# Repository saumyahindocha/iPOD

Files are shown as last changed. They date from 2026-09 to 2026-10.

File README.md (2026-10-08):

# iPOD — a DIY handheld music player

> A pocket-sized modern iPod built from scratch: Raspberry Pi Pico 2 W, Bluetooth streaming, hi-fi I2S DAC, and a touchscreen that shows album art.

A pocket-sized "modern iPod" built around the Raspberry Pi Pico 2 W. Pod receives audio from a phone over Bluetooth, plays it through a hi-fi I2S DAC, and shows album art on a touchscreen.

**Status:** breadboard prototyping. A custom PCB comes after full testing and optimisation on the breadboard.

## Goals

- **Bluetooth A2DP sink (core requirement):** phone → Pico 2 W → DAC → headphones
- **Now Playing screen** with full-bleed album art fading into an accent colour, and centred track text ("Poster" layout)
- **SD card playback** with a library browser, and a battery gauge with low-battery warning

## Hardware

| Part | Role |
|---|---|
| Raspberry Pi Pico 2 W | Main controller, Bluetooth Classic |
| Adafruit PCM5102 I2S DAC | Audio output |
| 2.8" 240×320 SPI touch display | UI and album art |
| microSD slot (on the display module) | Local playback |

The Pico 2 W replaced an earlier ESP32-S3 plan because the ESP32-S3 has no Bluetooth Classic, which A2DP needs.

## Wiring

Pins as of the perfboard build (8 Oct 2026); `sdk/common/pod_pins.h` is the source of truth.
They were re-chosen so 7 screen pins sit directly below their Pico pin on the perfboard;
see [docs/perfboard_build.pdf](docs/perfboard_build.pdf). The old breadboard layout is in git history.

### Display + touch (shared SPI0)

| Display pin | Pico 2 W |
|---|---|
| VCC | 3V3 (pin 36) |
| GND | GND |
| CS | GP12 (pin 16) |
| RESET | GP11 (pin 15) |
| DC | GP10 (pin 14) |
| SDI (MOSI) + T_DIN | GP7 (pin 10) |
| SCK + T_CLK | GP6 (pin 9) |
| LED | GP8 (pin 11) |
| SDO (MISO) | not connected |
| T_CS | GP5 (pin 7) |
| T_DO | GP4 (pin 6) |
| T_IRQ | GP3 (pin 5) |

Touch calibration (this board): both axes are reversed. Raw X ≈ 3540 at the left edge and ≈ 565 at the right; raw Y ≈ 3680 at the top and ≈ 380 at the bottom.

### PCM5102 DAC (I2S)

| DAC pin | Pico 2 W |
|---|---|
| VIN | 3V3 (pin 36) |
| GND | GND |
| DIN | GP13 (pin 17) |
| BCK | GP14 (pin 19) |
| WSEL (LRCK) | GP15 (pin 20) |
| MCK, DE, FIL, MU, FM | not connected |

### microSD (slot on the display module)

SD_CS → GP9; shares GP6 (SCK), GP7 (MOSI) and GP4 (MISO) with the display bus.

### Battery

100k/100k divider from the switched battery to GP28 (pin 34), 100 nF across the lower resistor.
A MAX17048 breakout on GP0 (SDA) / GP1 (SCL) is used instead if fitted.

## Firmware overview

Pod has two firmware tracks:

- **`sdk/` — the main firmware** (C, Raspberry Pi Pico SDK + BTstack). A home screen picks the source:
  - **Phone:** Bluetooth audio from the iPhone with **album art over AVRCP Cover Art**, volume slider synced with the phone, press-and-hold seeking.
  - **SD card:** MP3/WAV player with a touch library browser, tags and cover art, drag-to-seek, auto-advance through a folder.
  - Poster Now Playing screen rendered on the second core, battery icon with low-battery warning.
  See [sdk/README.md](sdk/README.md) for the test plan.
- **`firmware/` — Arduino bring-up sketches** used to test each part of the hardware on its own (LED, DAC, Bluetooth, screen, touch).

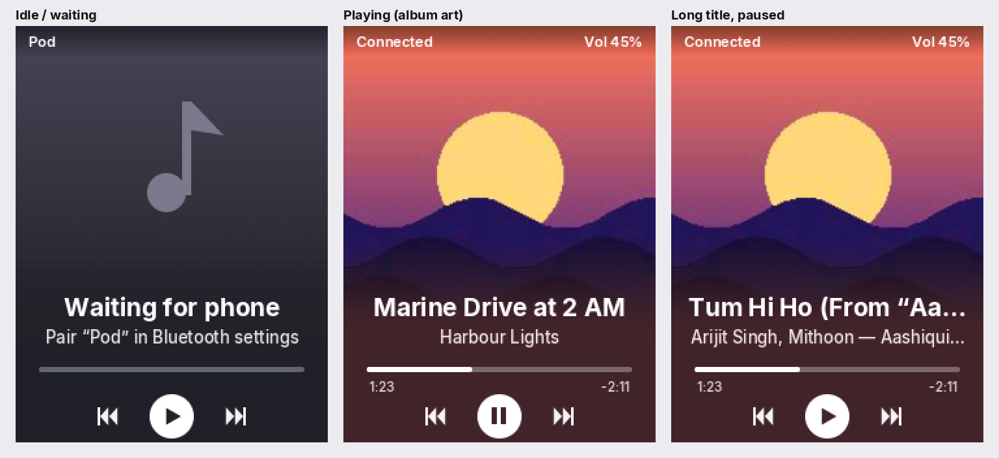
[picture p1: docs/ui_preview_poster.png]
Poster UI preview


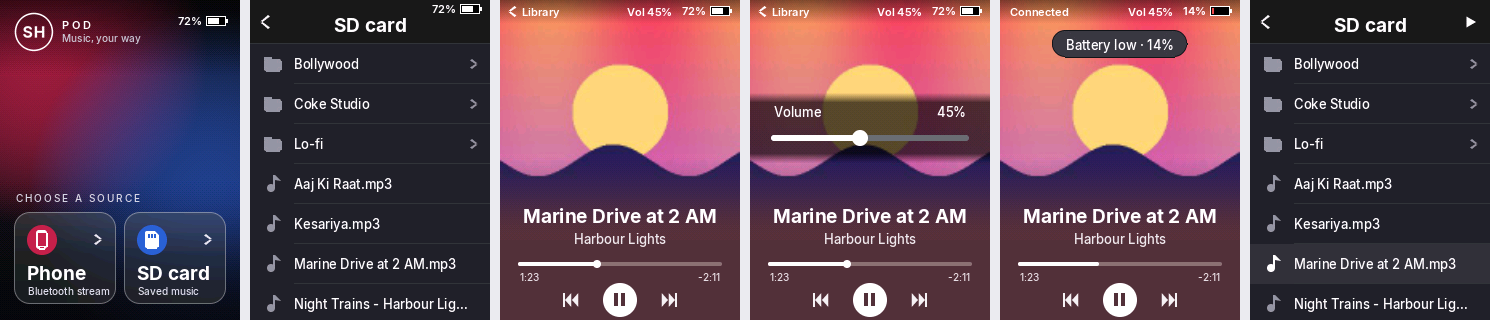
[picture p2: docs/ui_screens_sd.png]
Home, library, SD Now Playing, volume, low battery


## Building the firmware

The **Build SDK firmware** action compiles `sdk/` and publishes the `pod-sdk-firmware` artifact. The Arduino sketches are built by the **Build firmware** action as described below.

### Arduino sketches

Sketches live in `firmware/<name>/<name>.ino`. Every push that touches `firmware/` triggers the **Build firmware** GitHub Action, which compiles each sketch for the Pico 2 W with `arduino-cli` and the [arduino-pico](https://github.com/earlephilhower/arduino-pico) core. A `sketch.yaml` in a sketch folder can set its own board options (e.g. Bluetooth on), `firmware/libraries.txt` lists the Arduino libraries the build installs, and Pod's own libraries live in `firmware/libraries/` (e.g. `PodTouch`, the touch driver).

To flash: open the latest run under **Actions**, download the **pod-firmware** artifact, hold BOOTSEL while plugging in the Pico, and drag the `.uf2` onto the RP2350 drive.

| Sketch | What it does |
|---|---|
| `blink` | Blinks the onboard LED (build + flash check) |
| `tone_test` | 440 Hz tone through the DAC (I2S wiring check) |
| `bt_sink` | Bluetooth A2DP receiver named "Pod": phone → DAC → headphones |
| `display_test` | Colour test, title screen and touch dots on the ILI9341 + XPT2046 |
| `now_playing` | Bluetooth audio + Now Playing screen: track, artist, album and touch controls |

## Repository layout

```
sdk/        main firmware (Pico SDK, C)
firmware/   Arduino bring-up sketches (one folder per sketch)
.github/    GitHub Actions build
hardware/   KiCad PCB project (hardware/pod-pcb)
docs/       notes and datasheets
PROGRESS.md dated build log
```

## PCB, battery and enclosure

Rev A board (being drawn in EasyEDA Pro): a Pico 2 W soldered onto our board, the 2.8" screen module on sockets, USB-C charging, 1000 mAh LiPo with fuel gauge, PCM5102A DAC and headphone jack, play/pause button and power switch. The design spec is [docs/pcb-plan.md](docs/pcb-plan.md) and the EasyEDA workflow is [docs/easyeda-guide.md](docs/easyeda-guide.md). The older KiCad skeleton in `hardware/pod-pcb` was for a bare-RP2350 version and is no longer used.

## Progress

See [PROGRESS.md](PROGRESS.md).

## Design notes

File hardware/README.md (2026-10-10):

# hardware

| Folder | What's in it | Status |
|---|---|---|
| `perfboard/` | The build in progress: the Pico 2 W, screen, DAC and TP4056 charger on a 20 × 43-hole perfboard. The full guide (solder view, hole-by-hole map, front view, off-board wires, shopping list) is [`../docs/perfboard_build.pdf`](../docs/perfboard_build.pdf); `dac_wiring.pdf` is the stand-alone DAC sheet; `tools/` has the scripts that draw them | **Building** |
| `pod-pcb-easyeda/` | Rev A custom PCB drawn in EasyEDA Pro: 4-page schematic, assembly drawing, 1:1 fit test, and `fab/` with the Gerbers (outline fixed), BOM and pick-and-place, ready for JLCPCB | Designed, not ordered (about $90 assembled) |
| `pod-pcb/` | Early KiCad skeleton for a bare-RP2350 board | Superseded |

The design spec for the PCB is [`../docs/pcb-plan.md`](../docs/pcb-plan.md); the EasyEDA walkthrough is [`../docs/easyeda-guide.md`](../docs/easyeda-guide.md).
Pin assignments for both builds live in [`../sdk/common/pod_pins.h`](../sdk/common/pod_pins.h).

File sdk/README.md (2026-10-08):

# Pod bring-up kit: Pico 2 W + PCM5102 + 2.8" ILI9341/XPT2046

Pod's main firmware for **the breadboard wiring below**, built against **Pico SDK 2.3.1** and
**pico-extras sdk-2.3.1** for board `pico2_w`. They compile cleanly, and the
screen renderer was checked pixel-for-pixel on a PC, but they have **not been run
on real hardware yet**. Your breadboard is the first test.

| Firmware (`pod-sdk-firmware` artifact in Actions) | What it tests |
|---|---|
| `pod_display_test.uf2` | Screen + touch only: colours, geometry, touch calibration, paint |
| `pod_dac_test.uf2` | DAC only: quiet 440 Hz tone, LEFT → RIGHT → BOTH → silence |
| `pod.uf2` | **The main firmware.** Home screen → **Phone** (iPhone → Bluetooth → DAC with album art) or **SD card** (MP3/WAV player with library browser). Poster Now Playing screen, volume slider, seeking, battery icon |

---

## 1. Wiring (single source of truth: `common/pod_pins.h`)

Pico 2 W physical pin numbers are in brackets. GND pins: 3, 8, 13, 18, 23, 28, 33, 38.
**Never use GP23, GP24, GP25 or GP29.** The radio uses them.

Pins changed on 8 Oct 2026 for the perfboard build (7 screen pins sit directly below their
Pico pin there; see `docs/perfboard_build.pdf`). The breadboard layout is in git history.

### Display + touch (both on SPI0)
| Module pin | Pico 2 W | Note |
|---|---|---|
| VCC | 3V3 OUT (36) | |
| GND | GND | |
| CS | GP12 (16) | |
| RESET | GP11 (15) | |
| DC | GP10 (14) | |
| SDI(MOSI) | GP7 (10) | shared with T_DIN and SD_MOSI |
| SCK | GP6 (9) | shared with T_CLK and SD_SCK |
| LED | GP8 (11) | backlight (PWM) |
| SDO(MISO) | **not connected** | doesn't release the line; would corrupt touch readings |
| T_CLK | GP6 (9) | shared with SCK |
| T_CS | GP5 (7) | |
| T_DIN | GP7 (10) | shared with SDI |
| T_DO | GP4 (6) | SPI0 RX; shared with SD_MISO |
| T_IRQ | GP3 (5) | |

### PCM5102 DAC (Adafruit)
| DAC pin | Pico 2 W |
|---|---|
| VIN | 3V3 OUT (36) |
| GND | GND |
| DIN | GP13 (17) |
| BCK | GP14 (19) |
| WSEL | GP15 (20) (must be BCK + 1) |
| MCK, DE, FIL, MU, FM | leave unconnected |

Listening: DAC jack → headphones or a powered speaker (line level).

### SD card slot (on the back of the display module, shares SPI0)
| SD pin (4-pin header next to the card slot) | Pico 2 W |
|---|---|
| SD_CS | GP9 (12) |
| SD_SCK | GP6 (9) |
| SD_MOSI | GP7 (10) |
| SD_MISO | GP4 (6) |

### Battery level
Perfboard: 100k/100k divider from the switched battery to GP28 (34), 100 nF across the lower
resistor; the firmware reads it at start-up if it sees a voltage there. Optional instead: a
MAX17048 breakout on SDA → GP0 (1), SCL → GP1 (2). With neither, the battery icon stays hidden.

## 2. Before powering up (5 minutes, prevents most problems)
1. **Unplug USB.** Multimeter on resistance/continuity: 3V3 (36) to GND must NOT
   beep (no short). VBUS (40) to GND must NOT beep.
2. Continuity-check every jumper from the module pin to the Pico pin, especially
   the shared SCK/T_CLK and SDI/T_DIN connections.
3. Install a serial monitor: VS Code + Raspberry Pi Pico extension (built-in
   Serial Monitor), PuTTY, or the Arduino IDE Serial Monitor. The Pico appears
   as a COM port once running (any baud setting works over USB).

**Flashing any UF2:** hold **BOOTSEL**, plug in USB, release, then drag the
`.uf2` onto the `RP2350` drive. The board reboots by itself. Open the serial
monitor within ~1 s to catch the first lines.

---

## 3. Test sequence: one part at a time

### Step 1: screen + touch → `pod_display_test.uf2`
Pass criteria:
- Full-screen RED, GREEN, BLUE, WHITE, BLACK in that order (serial names each one).
- A white border with coloured corners: RED top-left, GREEN top-right, BLUE bottom-left, WHITE bottom-right.
- Tap the 4 yellow crosshairs. Serial prints a calibration block.
- Paint mode: dots land under the stylus. The red box clears the screen.

If it fails:
- White screen: SCK/MOSI/CS/DC/RESET wiring.
- Black screen: LED or VCC.
- Red and blue swapped: change `0x48` to `0x40` in `common/ili9341.c`.
- Touch dead: T_CS/T_DO/T_IRQ wiring. Check that the display's SDO is really disconnected.
- Speckles or garbage: lower `POD_TFT_BAUD` to 20 MHz in `pod_pins.h`.

### Step 2: DAC → `pod_dac_test.uf2`
A quiet tone plays: left ear, right ear, both, silence, repeating.
- Left and right swapped: BCK and WSEL are swapped.
- Silence: check DIN/BCK/WSEL and VIN.

### Step 3: Bluetooth + Poster UI → `pod.uf2`, choose **Phone**
1. **First boot runs touch setup:** tap the 4 dots. The calibration is saved to
   flash. To redo it later, **hold a finger on the screen for 2 seconds while plugging in USB**.
2. The **home screen** (SH logo, wallpaper, two glass buttons) asks Phone or SD card: tap **Phone**. The idle screen reads **"Waiting for phone"**.
   Tapping the **house icon** (top-left on Now Playing, top-right in the library) goes back to the home screen.
3. On the iPhone, go to Settings → Bluetooth and tap **"Pod xx:xx:…"**. If you
   paired an earlier Pod build, first open it there and choose **"Forget This
   Device"**, because iOS caches the old feature list.
4. Play something in Spotify. Within about 1–2 s you should see:
   - the album art full-bleed, fading into a colour taken from the cover
   - title, artist, the moving progress bar with elapsed and remaining time
   - serial lines: `Cover Art : connection established`, then `downloading thumbnail`, then
     `album art 200x200 … decoded`, then `frame rendered in N ms`
5. Tap **prev / play-pause / next** at the bottom of the screen. Spotify should
   respond. Serial: `Pod: touch command N sent`.
   **Press and hold** prev / next to rewind / fast-forward (release to stop).
   How far it scrubs depends on the app; Bluetooth has no "jump to time" command.
6. Move the iPhone volume slider. "Vol NN%" updates and the loudness changes.
7. **Tap the album art** to open the Pod's volume slider and drag it. The sound changes
   and the iPhone's volume slider follows. It closes by itself after 3 s.

---

### Home screen wallpaper (optional)
The home screen shows a full-screen picture behind the SH logo and the two glass buttons. Without one,
it shows generated garnet-and-blue art. To install your own (it lives in its own flash area, so
firmware updates don't erase it, and the picture never goes into the repo):

```
python3 tools/make_wallpaper.py my_photo.jpg --focus 0.55 --preview check.png
```
`--focus` picks the vertical crop (0 = top, 1 = bottom); look at `check.png`, then flash
`wallpaper.uf2` like firmware (BOOTSEL, drag). Flash `pod.uf2` again afterwards if needed; the two
never overwrite each other.

### Step 4: SD card player → `pod.uf2`, choose **SD card**
**Card:** FAT32 or exFAT, any size. Copy MP3 (CBR or VBR) or WAV (16/24-bit) files; folders are fine.
For cover art, embed a **baseline JPEG up to 32 KB** (about 300–500 px) in the MP3, or put
`cover.jpg` / `folder.jpg` in the album folder. Progressive JPEGs and PNGs show the placeholder.

1. Tap **SD card** on the home screen. The library lists folders first, then songs, A–Z.
   Drag to scroll, tap a folder to open it, **<** (top-left) to go up; at the top level it goes home.
2. Tap a song: it plays and the Poster screen shows its title, artist and cover.
   Serial: `Pod: SD card ready`, `Pod: playing /…/song.mp3 (MP3 44100 Hz, … ms)`.
3. **Drag the knob on the progress bar** to jump anywhere in the song.
4. **Hold ⏭ / ⏮** to scrub 5 s at a time; tap to skip. ⏮ restarts the song if more than 3 s in.
5. Tap the art for the volume slider. **< Library** (top-left) goes back to the list;
   the ▶ in the list header returns to the song.
6. At the end of a song the next one in the folder plays; at the end of the folder it stops.

Troubleshooting: "No SD card" → check SD_CS (GP7) and the three shared wires; "Card isn't FAT32 /
exFAT" → reformat; crackles while the screen redraws → report it (the display releases the bus every
24 rows, so this shouldn't happen).

### Battery icon and low-battery warning
With the gauge fitted, the status bar shows the percentage and a battery icon (green while
charging). Below **15 %** a "Battery low" message pops up once; it re-arms after charging.

## 4. Robustness tests (do all of these before the PCB)
| Test | Expected |
|---|---|
| 30-minute continuous play | No dropouts, clicks or resets |
| Skip tracks 10× quickly | Art and text catch up to the final track |
| Walk out of range (~10 m, a wall), come back | Audio stops, then reconnects |
| iPhone Bluetooth off/on | Pod returns to "Waiting…", then reconnects |
| Unplug and replug Pod | iPhone reconnects without re-pairing (keys are in flash) |
| Phone call during playback | Music pauses; call audio stays on the iPhone (call audio over Bluetooth isn't supported, by design) |
| Track with no artwork / podcast | Placeholder note is shown, no crash |
| Hindi/Devanagari title | Shows `?`. Expected for now (font has Latin only) |

## 5. Measure & tune (numbers to bring to the PCB design)
- **Screen SPI speed:** raise `POD_TFT_BAUD` from 30 MHz to 40 MHz, then 62.5 MHz. Keep the highest
  speed with zero glitches. Short PCB traces will allow the top speed.
- **Render time:** from `frame rendered in N ms` on serial. Target < 150 ms.
- **Audio glitches during track changes** (when art is drawn): there should be none,
  because drawing runs on the second core. Report it if you hear any.
- **Current draw:** use a USB power meter, or a multimeter in series with 5 V. Measure
  idle, streaming, and streaming with the backlight off. These numbers size the
  battery and regulator.
- **Bluetooth range:** in open space and through one wall. It depends on antenna
  placement, which matters for the PCB/enclosure.

Write these numbers down; they are the inputs to the PCB design phase.

---

## What's in the firmware

**SD mode** (`sd_player/`): FatFs (read-only, FAT32 + exFAT) over a small SPI SD driver; minimp3 for MP3,
WAV 16/24-bit; ID3v2.2–2.4 + ID3v1 + WAV INFO tags; Xing/VBRI headers for exact duration and VBR
seeking. `tools/test_track_meta.c` tests this on a PC against real files; `tools/preview/` renders the
screens on a PC.

**Phone mode** (vs. upstream `a2dp_sink_demo`)
All changes are marked `Pod patch`.
1. **Software volume.** Upstream ignores volume, which makes the iPhone slider do nothing at full scale.
2. **Sample-rate change handling** (44.1/48 kHz) so audio never plays at the wrong pitch.
3. **Album art over Bluetooth** (AVRCP Cover Art), downloaded to RAM automatically on every track change.
4. **Option C Poster UI on core 1:** 240×240 art, smoothstep fade into an accent
   colour, dithered gradients, anti-aliased Inter text, live progress, touch
   controls. Core 0 keeps Bluetooth and audio. Touch calibration is stored in flash.
5. Device name "Pod", logs over USB serial.

## Rebuilding

**On GitHub (normal way):** every push that changes `sdk/` runs the **Build SDK firmware**
action. Download the `pod-sdk-firmware` artifact from the run and drag the `.uf2` onto the Pico.

**Locally:**
Install the **Raspberry Pi Pico** VS Code extension (SDK 2.3.1 + toolchain), then:
```
git clone -b sdk-2.3.1 https://github.com/raspberrypi/pico-extras.git
cmake -B build -G Ninja -DPICO_SDK_PATH=... -DPICO_EXTRAS_PATH=... -DCMAKE_BUILD_TYPE=Release
ninja -C build
```
Fonts are pre-generated. To change sizes or weights, edit `tools/gen_fonts.py` and run
`python3 tools/gen_fonts.py` (needs Pillow).

## Credits / licences
Inter font: SIL Open Font License (`third_party/inter/LICENSE.txt`). TJpgDec
by ChaN (`third_party/tjpgd/LICENSE.txt`). BTstack via the Pico SDK (Raspberry
Pi's licence covers RP2xxx use). 8x8 font in the test app: public domain.

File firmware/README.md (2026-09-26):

# firmware
Pico 2 W source code goes here.

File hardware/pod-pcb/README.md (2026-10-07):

# Pod PCB (Rev A)

KiCad project for the Pod board. **The spec it follows is [docs/pcb-plan.md](../../docs/pcb-plan.md)**:
RP2350A + RM2 Bluetooth, PCM5102A DAC, BQ24074 USB-C charging with power path, MAX17048 fuel gauge,
TPS63802 3.3 V buck-boost, 16 MB flash + 8 MB PSRAM, sockets for the 2.8" ILI9341 screen module,
play/pause button and power/hold switch. 4 layers, 0.8 mm, 50 × 94 mm.

| File | What's in it |
|---|---|
| `pod-pcb.kicad_pro` | Project, with JLCPCB-friendly rules and net classes (Power, USB) |
| `pod-pcb.kicad_sch` | Overview sheet linking the five blocks |
| `power.kicad_sch` … `screen_controls.kicad_sch` | One sheet per block, each with its checklist printed on it |
| `pod-pcb.kicad_pcb` | 4-layer board: outline, module area, M3 holes, battery area, RM2 antenna keep-out |

**Designing in EasyEDA instead?** Follow [docs/easyeda-guide.md](../../docs/easyeda-guide.md); the spec is the same.

**Workflow (KiCad):** open the project in KiCad 9 (it upgrades these KiCad 7 files), draw one sheet to its
checklist, delete the checklist box, commit and push. Each sheet is reviewed against the spec before
the next one. Start with **Power**.

Before routing, measure the screen module (outline, hole centres, header positions) and update
the outline, the holes and the J3/J4 socket positions.

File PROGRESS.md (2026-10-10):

# Pod — build log

Newest entries at the top. Each entry: what was done, what broke, what's next.

## 2026-10-10 (later) — Device built and touch working

**Done**
- Whole perfboard built in one night: Pico, screen, DAC, links and wires; powered from the Pico's USB until the battery arrives (TP4056 and battery not fitted yet, firmware hides the battery icon)
- Firmware boots to the home screen on the new pin map; touch now works after a fresh 4-dot calibration

**Fixed**
- Touch read nothing: the data link from Pico pin 6 (GP4) to the screen's T_DO (perfboard holes F8–F9–F10) was open. The pressed signal (T_IRQ) worked, so the setup dots "accepted" garbage readings (all 0 or all 8191) and the home screen rightly refused the resulting calibration. Found by printing the raw readings on the screen; fixed by resoldering the link
- Firmware hardening from the hunt: MISO pulled up; a tap counts on Z1 alone (Z2 unreliable here); readings above 4095 rejected as "line open"; new calibration magic so the stale breadboard calibration is ignored; battery init runs after the home screen
- Two diagnostic firmwares added: `pod_touch_doctor` (names the wire to check) and `pod_touch_setup` (calibrate with live raw numbers, test, save)

**Next**
- Test SD playback and Bluetooth from the phone
- Software design updates and new features (Ash's list)
- Fit the TP4056, switch and battery when they arrive

## 2026-10-10 — Perfboard build under way

**Done**
- Started soldering the perfboard: screen sockets in and the screen fitted, DAC mounted under the screen with its jack at the board edge
- Got the DAC's real pin order from Adafruit's own board files (two rows: DE/FIL/MCK/MU/FM/3V, and VIN/GND/WSEL/DIN/BCK/Lout/G/Rout) and matched it to photos of the build
- DAC added to the main perfboard guide: pins in holes N34–N39 and T35–T40, five numbered wires (12–16) to Pico pins 36, 18, 20, 17, 19; hole map and front view updated. Multimeter check before wiring: N35 (GND) must beep to the jack's sleeve
- Battery divider now uses two 150 kΩ resistors (on hand); firmware detection threshold lowered so 100–150 kΩ dividers are found even on a low battery. Local build passes
- Repo tidy-up: `hardware/pod-pcb-easyeda/` holds the finished PCB design (schematic, assembly drawing, 1:1 fit test, Gerbers with the outline fix, BOM, pick-and-place) so it can be ordered later; `hardware/perfboard/` holds the DAC sheet and the scripts that draw the build guide

**Notes**
- Spare 10 µF / 100 µF electrolytics aren't suitable for the 100 nF filter on the battery divider (their leakage would read the battery low); buy a 100 nF ceramic or leave it out

**Next**
- Finish the 7 links and wires 1–11, test screen, touch and SD on USB power
- Solder the DAC pins, check N35 to the jack sleeve, then wires 12–16 and test audio
- TP4056, switch and battery last, after the continuity checks in the guide

## 2026-10-08 (later) — Switched to a perfboard build

**Done**
- JLCPCB quote for the assembled PCB came to about $90, too much for one prototype; the PCB design stays in the repo for later
- Planned a perfboard version with the same layout and the same Pico pins (`docs/perfboard_build.pdf`): Pico 2 W in sockets at the top, screen on sockets below it, TP4056 USB-C charger and the Adafruit PCM5102 DAC at the bottom edge, 1000 mAh LiPo on the back
- Power: TP4056 OUT+ → slide switch → 1N5819 → VSYS, so the Pico's USB can stay plugged in for flashing; 100k/100k divider on GP28 for the battery level
- Re-chose the GPIO map so 7 screen pins sit directly under their Pico pins (short solder links instead of wires): on-board wires down from 18 to 11. Display on SPI0 GP4/6/7, CS GP12, DC GP10, RST GP11, LED GP8, T_CS GP5, T_IRQ GP3, SD_CS GP9; DAC DIN GP13, BCK GP14, WSEL GP15. Firmware pins and CMake I2S pins updated; local build passes
- Firmware reads the battery from the GP28 divider when no MAX17048 answers (percent from a LiPo voltage curve, charging inferred from rising voltage); the optional gauge moved to GP0/GP1

**Next**
- Buy parts, build, test screen/touch/SD on USB power first, then audio, then battery
- Check the battery percentage against a multimeter once the battery is in

## 2026-10-08 — PCB routed and exported

**Done**
- Switched the board to carry the Pico 2 W itself (soldered on through its headers) instead of a bare RP2350; dropped the TPS63802 regulator and USB ESD chip (USB-C is charge-only)
- All four schematic sheets drawn and reviewed: Power, Pico, Audio (PCM5102A + PJ-342 jack with headphone detect), Screen (14-pin and 4-pin sockets, play button)
- PCB 52 × 109 mm, 2 layers: placed, autorouted with hand-drawn power stubs between the Pico pins, GND pours on both layers, antenna notch and keep-out. DRC clean apart from the expected notch item
- Exported Gerbers, BOM (23 lines, all LCSC) and pick-and-place; checked drill sizes, outline, copper and positions

**Fixed in review**
- Many routing problems: power nets too wide to pass between header pins (power width 0.4 mm plus 0.3 mm stubs), GND islands, duplicate vias, stitching vias with no copper, pours not rebuilt
- Gerber outline had a stray 6.35 mm line from the jack footprint, 2.2 mm inside the bottom edge, which the fab would have milled as a slot; removed from the outline file

**Next**
- Paper 1:1 fit test with the Pico and screen module, then order from JLCPCB (top-side assembly; hand-solder the Pico and screen sockets)
- Firmware: headphone detect, charge/power-good status, play button

## 2026-10-07 (evening) — Power sheet drawn in EasyEDA

**Done**
- Moved PCB design to EasyEDA Pro (online); wrote a beginner guide with click-by-click checklists (`docs/easyeda-guide.md`)
- Sheet 1 (Power) drawn and reviewed: USB-C + ESD, BQ24074 charger, battery connector, power switch, TPS63802 3.3 V regulator, MAX17048 gauge
- Resistor values changed to standard JLCPCB Basic parts: ISET 1.8 kΩ (0.49 A charging), ILIM 1.2 kΩ (1.34 A input limit), regulator feedback 56 kΩ / 10 kΩ (still 3.30 V)

**Fixed in review**
- Charger IN, the second OUT pin and the second BAT pin were unconnected; the two 22 µF output capacitors were in series; the gauge's 1 µF capacitor was missing; regulator PG label added

**Changed**
- Switched the board to Ash's own **Pico 2 W**, soldered on, instead of a bare RP2350A + RM2 radio: no chip, flash, PSRAM, crystal, radio or 3.3 V regulator to design, and 2 layers instead of 4
- The Pico sits in a 23 mm strip above the screen module with a 9 × 14 mm cut-out under its antenna (Raspberry Pi's carrier-board rule); board 52 × 109 mm, Pod about 57 × 115 × 24 mm
- Power: charger output feeds the Pico's VSYS; the power switch grounds the Pico's 3V3_EN; the Pico's 3V3 pin powers the screen, DAC and gauge. USB-C charges, the Pico's micro-USB programs
- Same GPIOs as the breadboard, so `pod.uf2` runs unchanged

- All four schematic pages drawn in EasyEDA and reviewed: Power, Pico (as two 1×20 through-hole headers J6/J7, LCSC C50981), Audio (PCM5102A, PJ-342 jack C668606 with detect on its switch contact), Screen (sockets C5307340 / C2897367, side button C530670)

**Next**
- Export the BOM for a part check; convert to PCB and place parts using the layout in `docs/pcb-plan.md`

## 2026-10-07 (later) — Home screen, SD player, battery

**Done (built and tested on a PC, waiting for the SD card + wires to test on hardware)**
- Home screen: choose **Phone** or **SD card**; tapping the top-left corner returns to it
- Home screen redesign: full-screen wallpaper (installed separately as `wallpaper.uf2` via `sdk/tools/make_wallpaper.py`, kept out of the repo), SH monogram + POD wordmark, frosted-glass buttons that blur the picture behind them, garnet/blue accents; generated fallback art when no wallpaper is installed
- SD card player in `sdk/sd_player/`: library browser (folders first, A–Z, drag to scroll), MP3 + WAV, tags and cover art (embedded JPEG or cover.jpg), drag-to-seek, hold-to-scrub, auto-advance
- Track reader tested on a PC with CBR/VBR MP3, MPEG-2 mono, ID3v2.3/2.4 (UTF-8 and UTF-16), WAV 16/24-bit: tags, covers, durations and seek positions all correct
- SPI bus lock so the screen, touch and SD card share SPI0; full-screen updates release the bus every 24 rows
- Battery icon + "Battery low" warning below 15 %, from a MAX17048 fuel gauge (hidden when none is fitted)
- Going home was fiddly (tiny target at the top edge; SD mode needed backing out of every folder): added a house-icon Home button with a large touch area on Now Playing (both modes) and in the library header, a "Going home…" message, and recalibration now needs a 1.5 s hold at power-up so a quick tap during the restart can't trigger it
- Main firmware renamed to `pod.uf2`; core-0 stack raised to 4 KB for the MP3 decoder and FatFs

**PCB Rev A decisions**
- RP2350A chip + Raspberry Pi RM2 radio on our own board; keep the 2.8" resistive screen module, plugged into sockets; 1000 mAh LiPo (503450); play/pause/wake button + power/hold slide switch
- Everything else on the board: USB-C + BQ24074 charger with power path, MAX17048 gauge, TPS63802 3.3 V buck-boost, PCM5102A DAC + jack, 16 MB flash, 8 MB PSRAM
- Board 50 × 94 mm (module footprint + 8 mm antenna tab so the screen doesn't block Bluetooth)
- Screen module measured from a photo (holes, header and SD holder positions); print-out check template in `docs/screen_template_1to1.pdf`
- The module's SD holder sits in the gap under it, so the 1000 mAh battery moved to the underside of our board; Pod about 55 × 100 × 24 mm
- Spec with every connection in `docs/pcb-plan.md`; KiCad project started in `hardware/pod-pcb` (five sheets with checklists, 4-layer board outline, rules)

**Next**
- Print the 1:1 template and check it against the module
- Draw Sheet 1 (Power) in KiCad, push for review
- Wire the SD header (CS GP7, SCK GP18, MOSI GP19, MISO GP20), test SD mode

## 2026-10-07 — First firmware running

**Done**
- Rebuilt the breadboard circuit cleanly against the final pin map (README)
- Set up a GitHub Actions build: every push compiles all sketches in `firmware/` for the Pico 2 W and publishes `.uf2` files to flash by drag-and-drop
- `blink` works: build and flashing pipeline confirmed
- `tone_test` works: steady 440 Hz tone through the PCM5102 DAC, so the I2S wiring (GP9/GP10/GP11) is confirmed
- `bt_sink` works: iPhone pairs with "Pod" and streams Spotify through the DAC to headphones (core requirement met)
- `display_test` works: screen and touch both respond
- Calibrated touch from corner readings: both axes run backwards (dots were landing in the opposite corner)
- Touch needed a hard press: the XPT2046_Touchscreen library has a fixed pressure cutoff of 300. Wrote `PodTouch`, our own driver with an adjustable threshold (set to 60 after testing), extra averaging and the calibration built in
- `now_playing` works: Bluetooth audio, track info on screen and touch controls together (first combined firmware); only album art is missing
- Recovered the full Poster firmware from an earlier design session (Pico SDK, C, with album art over AVRCP Cover Art) and added it as `sdk/`, with its own GitHub Actions build. Touch threshold lowered from 300 to 60 there too
- Pod-side controls in `sdk/`: tap the album art for a volume slider (synced with the iPhone via AVRCP absolute volume), press-and-hold prev/next to rewind/fast-forward (built, awaiting hardware test)

**Fixed**
- Breadboard wiring didn't match the plan: T_DO was on GP21, RESET on GP20, MOSI on GP21 and display MISO connected. Moved to RESET → GP21, T_DO → GP20, MOSI → GP19, MISO disconnected (GP21 isn't a valid SPI0 data pin)
- Local Arduino IDE compiles failed because the laptop's antivirus removed parts of the compiler toolchain; moved compiling to GitHub Actions

**Next**
- Test the `sdk/` Poster firmware on hardware: album art download, colour fade, progress bar, volume, touch controls
- Run the robustness and measurement tests in sdk/README.md before PCB design
- Planned: Bluetooth output to AirPods for SD music

## 2026-09-26 — Repository started

**Done**
- Settled on the Raspberry Pi Pico 2 W (Bluetooth Classic for A2DP), replacing the earlier ESP32-S3 plan
- Display, touch and PCM5102 DAC wired on the breadboard
- Chose the "Poster" Now Playing layout: full-bleed album art fading into an accent colour

**Fixed**
- Display RESET and touch T_DO were swapped: RESET is now GP21 and T_DO is GP20
- Display SDO/MISO left disconnected so it doesn't fight the touch controller on the shared bus

**Next**
- Get Bluetooth A2DP streaming working from the phone to the DAC
- Bring up the display and touch
- Buy a microSD card for the local playback track

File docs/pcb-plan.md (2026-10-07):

# Pod — PCB Rev A design spec

The design for the first Pod board. One section per schematic page, with every connection written
out. It's drawn in **EasyEDA Pro**; `docs/easyeda-guide.md` explains how, click by click.

**Change on 7 Oct 2026 (evening):** the board now carries Ash's own **Raspberry Pi Pico 2 W**,
soldered on, instead of a bare RP2350A chip and RM2 radio. This removes the chip, flash, PSRAM,
crystal, radio and 3.3 V regulator from our board (the Pico has all of them), drops the radio page,
and makes a 2-layer board enough. The KiCad skeleton in `hardware/pod-pcb/` was for the old
version and is no longer used.

## Decisions

| # | Decision | Choice |
|---|---|---|
| 1 | Main board | **Raspberry Pi Pico 2 W module**, soldered onto our PCB (through its pin headers or castellated edge) |
| 2 | Screen | **Keep the 2.8" 240×320 resistive module** (ILI9341 + XPT2046 + microSD slot) |
| 3 | Screen mounting | **The red module plugs into sockets on our PCB** |
| 4 | Battery | **1000 mAh single-cell LiPo, ~5 mm thick** (503450, with protection board), **on the underside of our board** |
| 5 | Controls | **Play/pause + wake button** and an **iPod-style power/hold slide switch** |
| 6 | Ports | **USB-C for charging** (bottom edge); the **Pico's micro-USB for programming** (left side, top) |

On our board: USB-C charging socket, BQ24074 charger with power path, MAX17048 fuel gauge, power
switch, PCM5102A DAC and headphone jack, the sockets for the screen module, and the play button.

**Size:** board **52 × 109 mm**, Pod about **57 × 115 × 24 mm**. The Pico sits in a 23 mm strip
at the top, beyond the screen module, so its antenna isn't covered (see Layout).

## Firmware compatibility

The Pico uses exactly the breadboard pins, so `pod.uf2` runs on the board unchanged. New on the
board: charger status pins, the button, headphone detect and a DAC mute pin. The firmware gets
small additions for these after bring-up.

## How the power works

- **USB-C** → `VBUS` → BQ24074 charger → `VSYS` → the Pico's **VSYS** pin. The charger runs the Pod
  from USB and charges the battery at the same time; without USB it runs it from the battery.
- The Pico's own regulator makes **3.3 V** from VSYS. Its **3V3** pin powers the screen, DAC and
  fuel gauge. Keep the total 3V3 load under **300 mA** (the screen backlight is the largest at
  about 80 mA, so there's plenty of margin).
- **SW1** pulls the Pico's **3V3_EN** pin to GND for *off*: the Pico, screen and DAC lose power;
  the charger still charges. The off-state drain is about 0.07 mA (over a year on a full charge).
- The Pico's **VBUS** pin is joined to our `VBUS`, so the micro-USB cable can charge too.
  **Plug in only one cable at a time.**

---

## Parts list (Rev A)

Prefer JLCPCB **Basic** parts for resistors and capacitors (cheaper assembly).

| Ref | Part | MPN (example) | Package | Notes |
|---|---|---|---|---|
| U1 | **Raspberry Pi Pico 2 W** | — (Ash's own) | 51 × 21 mm module | hand-soldered through its pin headers; drawn as two 1×20 2.54 mm TH headers **J6** (Pico pins 1–20) and **J7** (pins 21–40, J7 pin n = Pico pin 20 + n), not in the BOM |
| U2 | Charger + power path | BQ24074RGTR | VQFN-16 3×3 | |
| U3 | Fuel gauge | MAX17048G+T10 | TDFN-8 2×2 | firmware already supports it |
| U8 | Audio DAC | PCM5102APWR | TSSOP-20 | |
| J1 | USB-C socket (charging) | HRO TYPE-C-31-M-12 | 16-pin SMD | |
| J2 | Battery connector | JST S2B-PH-SM4-TB | PH 2.0 mm | **check your battery's polarity** |
| J3 | Screen socket | ZHOURI PM2.54-1*14 (LCSC C5307340), 1×14 female, 2.54 mm, 8.5 mm tall | THT | module's main pins |
| J4 | SD socket | HCTL PM254-1-04-Z-8.5 (LCSC C2897367), 1×4 female, 8.5 mm tall | THT | module's SD pins |
| J5 | Headphone jack | SHOU HAN **PJ-342** (LCSC C668606) | SMD, 3.5 mm, two NC switches | 6 / 3 = the two springs (left / right channel), 7 / 4 = their switch contacts, 5 and 2 = ground contacts |
| SW1 | Power/hold switch | MSK-12C02 | SPDT side slide | |
| SW2 | Play/pause/wake | Kinghelm KH-3635-CAJ (LCSC C530670), side-push SMD | SMD | on the board edge |
| FB1 | Ferrite bead | Sunlord GZ1608D601TF (LCSC C1002, Basic) | 0603 | DAC analog supply, 600 Ω @ 100 MHz |
| — | Resistors, capacitors | values per page below | 0402 (bulk caps 0603/0805) | |
| BT1 | Battery | 1000 mAh LiPo, 503450, protection PCB, JST-PH lead | | off-board |

---

## Sheet 1 — Power

**Nets:** `VBUS` (USB 5 V), `VSYS` (charger output, 3.6–4.4 V, to the Pico), `VBAT` (cell),
`3V3` (from the Pico), `3V3_EN`, `GND`.

**J1 USB-C (charging only)**
- VBUS pins (A4, A9, B4, B9) → `VBUS`. GND pins (A1, A12, B1, B12) and shell → `GND`.
- CC1 (A5) → **5.1 kΩ** → GND. CC2 (B5) → **5.1 kΩ** → GND. *(Without these, USB-C chargers give 0 V.)*
- D+ (A6, B6), D− (A7, B7), SBU1, SBU2 → not connected. *(Data goes through the Pico's micro-USB.)*

**U2 BQ24074 (charger with power path)**
- IN → `VBUS`, with **4.7 µF** to GND.
- Both OUT pins → `VSYS`, with **10 µF** to GND.
- Both BAT pins → `VBAT`, with **10 µF** to GND.
- ISET → **1.8 kΩ** → GND → charge current = 890 / 1800 ≈ **0.49 A**.
- ILIM → **1.2 kΩ** → GND → input limit = 1610 / 1200 ≈ **1.34 A** (1.0 kΩ would exceed the 1.5 A maximum).
- ITERM → **3.0 kΩ** → GND → charging ends at 0.03 × 3000 / 1800 ≈ **50 mA**.
- TS → **10 kΩ** → GND.
- EN2 → `VBUS`, EN1 → GND (input limit set by ILIM). CE → GND. SYSOFF → GND. TMR → not connected.
- CHG (low = charging) → `CHG_N` → GP28, **100 kΩ** to `3V3`.
- PGOOD (low = USB present) → `PGOOD_N` → GP27, **100 kΩ** to `3V3`.
- VSS and exposed pad → GND.

**J2 battery** — pin 1 → `VBAT`, pin 2 → `GND`, mounting tabs → GND. Check the cell's polarity first.

**U3 MAX17048 (fuel gauge)**
- VDD → `VBAT` with **1 µF** to GND. CELL → `VBAT`. GND, CTG, QSTRT, exposed pad → GND.
- SDA → `I2C_SDA` (GP4), SCL → `I2C_SCL` (GP5); **4.7 kΩ** pull-ups to `3V3`.
- ALRT → `GAUGE_ALRT_N` → GP2, **10 kΩ** to `3V3`.

**SW1 power/hold switch (SPDT)** — middle (common) → `3V3_EN`; one side → `GND` (off); other side →
not connected (on: the Pico's own 100 kΩ pull-up holds 3V3_EN high).

*(No 3.3 V regulator and no USB ESD chip any more: the Pico has both.)*

## Sheet 2 — Pico 2 W

Every Pico pin, by its number on the Pico (pin 1 is next to the USB connector):

| Pin | Pico | Net | | Pin | Pico | Net |
|---|---|---|---|---|---|---|
| 1 | GP0 | not connected | | 21 | GP16 | `LCD_DC` |
| 2 | GP1 | `HP_DET` | | 22 | GP17 | `LCD_CS` |
| 3 | GND | `GND` | | 23 | GND | `GND` |
| 4 | GP2 | `GAUGE_ALRT_N` | | 24 | GP18 | `SPI0_SCK` |
| 5 | GP3 | not connected | | 25 | GP19 | `SPI0_MOSI` |
| 6 | GP4 | `I2C_SDA` | | 26 | GP20 | `SPI0_MISO` |
| 7 | GP5 | `I2C_SCL` | | 27 | GP21 | `LCD_RST` |
| 8 | GND | `GND` | | 28 | GND | `GND` |
| 9 | GP6 | `BTN_PLAY_N` | | 29 | GP22 | `TOUCH_CS` |
| 10 | GP7 | `SD_CS` | | 30 | RUN | not connected |
| 11 | GP8 | not connected | | 31 | GP26 | `TOUCH_IRQ` |
| 12 | GP9 | `I2S_DIN` | | 32 | GP27 | `PGOOD_N` |
| 13 | GND | `GND` | | 33 | AGND | `GND` |
| 14 | GP10 | `I2S_BCK` | | 34 | GP28 | `CHG_N` |
| 15 | GP11 | `I2S_LRCK` | | 35 | ADC_VREF | not connected |
| 16 | GP12 | `DAC_XSMT` | | 36 | 3V3 (out) | `3V3` |
| 17 | GP13 | `LCD_LED` | | 37 | 3V3_EN | `3V3_EN` |
| 18 | GND | `GND` | | 38 | GND | `GND` |
| 19 | GP14 | not connected | | 39 | VSYS | `VSYS` |
| 20 | GP15 | not connected | | 40 | VBUS | `VBUS` |

The 3 debug pins (SWCLK, GND, SWDIO) at the antenna end: not connected; they sit over the antenna
cut-out. Add **10 µF** from `3V3` to GND near pin 36 for the screen's backlight current.

## Sheet 3 — Audio (PCM5102A + jack)

- Pin 1 CPVDD → `3V3`, 100 nF + 10 µF. Pin 3 CPGND → GND.
- Pins 2 CAPP / 4 CAPM: **2.2 µF** between them. Pin 5 VNEG → **2.2 µF** to GND.
- Pin 8 AVDD → FB1 ferrite from `3V3`, then 10 µF + 100 nF to GND. Pin 9 AGND → GND.
- Pin 20 DVDD → `3V3`, 100 nF + 10 µF. Pin 19 DGND → GND. Pin 18 LDOO → **1 µF** to GND.
- Pin 12 SCK → GND (internal PLL makes the master clock from BCK, as on the breadboard).
- Pin 13 BCK ← `I2S_BCK` (GP10). Pin 14 DIN ← `I2S_DIN` (GP9). Pin 15 LRCK ← `I2S_LRCK` (GP11).
- Pins 10 DEMP, 11 FLT, 16 FMT → GND.
- Pin 17 XSMT ← `DAC_XSMT` (GP12), R21 **10 kΩ** to GND, so the DAC is muted until the firmware unmutes
  it. This removes the pop at power-on and between tracks.
- Pin 6 OUTL → R22 **470 Ω** → `HP_L` (jack tip), **2.2 nF** from `HP_L` to GND. Pin 7 OUTR → R23 **470 Ω** → `HP_R` (jack ring 1), **2.2 nF** from `HP_R` to GND.
- **J5 jack (PJ-342, C668606)**, pins from the SHOU HAN drawing: 5 and 2 → GND (ground contacts);
  6 (left spring) → `HP_L`; 3 (right spring) → `HP_R`; 7 (left spring's switch contact) → R24
  **4.7 kΩ** → `HP_DET`; 4 (right spring's switch contact) → not connected.
- *How detect works:* with no plug, spring 6 rests on contact 7, so GP1 reads low through the DAC
  output. A plug lifts the spring and GP1 reads high (internal pull-up). The 4.7 kΩ limits current
  into GP1 when the music swings below 0 V. Firmware: keep the DAC muted (XSMT low) unless
  headphones are in. If left and right come out swapped at bring-up, swap them in firmware.
- The PCM5102A is a line-level output; it drives earbuds at modest volume. If it's too quiet once
  built, a TPA6132A2 headphone amp can go between the DAC and the jack on Rev B.

## Sheet 4 — Screen sockets and controls

**J3 1×14 socket for the red module** (pin order as printed on the module, left to right):

| J3 pin | Module | Net |
|---|---|---|
| 1 | VCC | `3V3` |
| 2 | GND | `GND` |
| 3 | CS | `LCD_CS` (GP17) |
| 4 | RESET | `LCD_RST` (GP21) |
| 5 | DC | `LCD_DC` (GP16) |
| 6 | SDI (MOSI) | `SPI0_MOSI` (GP19) |
| 7 | SCK | `SPI0_SCK` (GP18) |
| 8 | LED | `LCD_LED` (GP13) |
| 9 | SDO (MISO) | **not connected** (the screen doesn't release the line) |
| 10 | T_CLK | `SPI0_SCK` |
| 11 | T_CS | `TOUCH_CS` (GP22) |
| 12 | T_DIN | `SPI0_MOSI` |
| 13 | T_DO | `SPI0_MISO` (GP20) |
| 14 | T_IRQ | `TOUCH_IRQ` (GP26) |

**J4 1×4 socket for the module's SD pins** — SD_CS → `SD_CS` (GP7), SD_MOSI → `SPI0_MOSI`,
SD_MISO → `SPI0_MISO`, SD_SCK → `SPI0_SCK`. Match the pin order printed next to the module's card slot.

**SW2 play/pause/wake** — one side → `BTN_PLAY_N` (GP6, internal pull-up), other side → GND; 100 nF across it.

**Mounting** — four M2.5 holes matching the module's corner holes; M2.5 nylon standoffs, the same height as
the sockets, hold the module firmly so the sockets don't carry the screen's weight.

---

---

## Layout

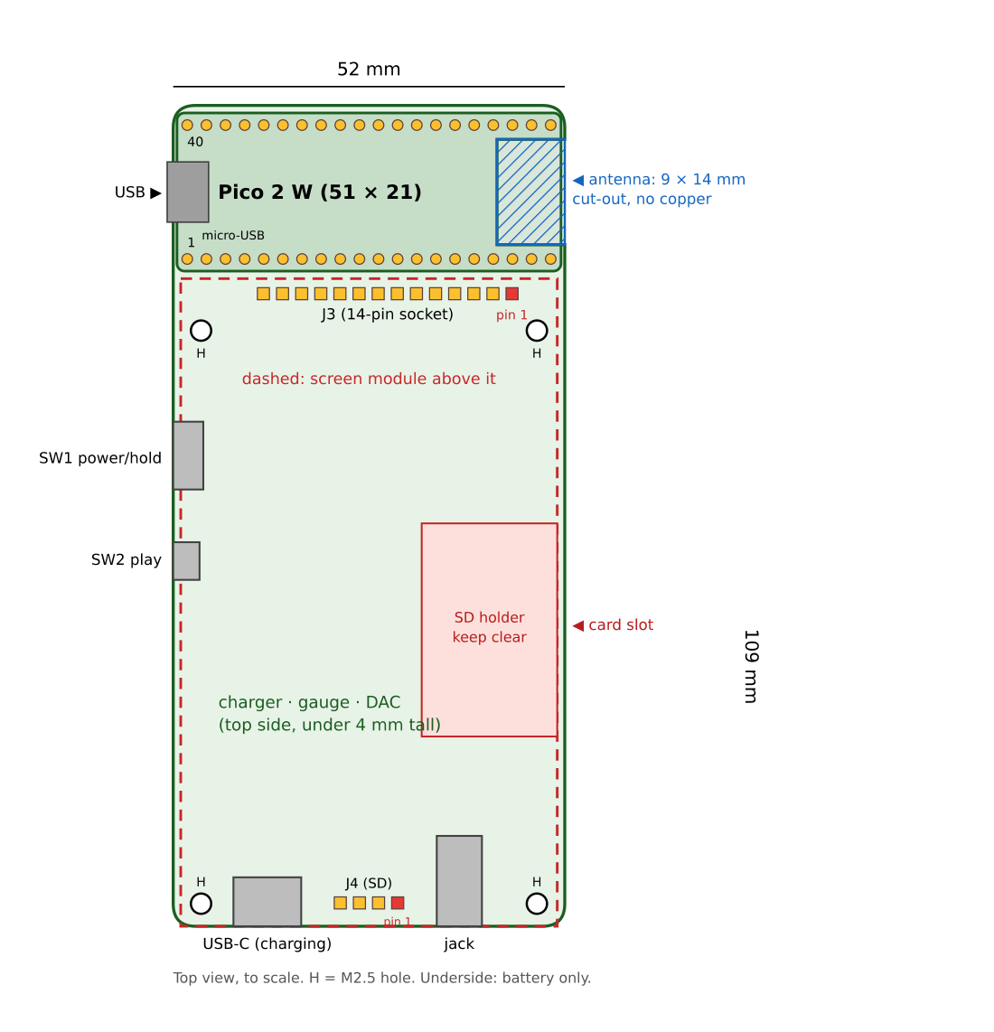
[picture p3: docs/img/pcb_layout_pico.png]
Top view of the board, to scale


All positions in mm from the board's **top-left corner**. The screen module sits 1 mm in from the
left edge and starts 23 mm down, and everything under it is **mirrored**, because the module faces
down onto our board.

| What | Where |
|---|---|
| Board outline | 52 × 109 mm, 3 mm corner radius |
| **Antenna cut-out** | notch in the right edge, **x 42.5–52, y 4.5–18.5** (9 × 14 mm, open to the edge). No copper on any layer within 2 mm of it |
| **Pico 2 W** (J6 + J7) | centre (26.0, 11.5); USB end at the **left** edge. **J6** pin 1 (Pico pin 1) at (1.87, 20.39), pins running right to (50.13, 20.39). **J7** pin 1 (Pico pin 21) at (50.13, 2.61), pins running left to (1.87, 2.61) |
| M2.5 holes (2.7 mm) | (3.7, 29.9), (48.3, 29.9), (3.7, 106.0), (48.3, 106.0) |
| J3 14-pin socket | pin 1 (VCC) at **(45.0, 25.0)**; pins 2–14 every 2.54 mm to the **left** (pin 14 at 12.0) |
| J4 4-pin SD socket | pin 1 (SD_CS) at **(29.8, 105.9)**; pins 2–4 to the left (pin 4 at 22.2) |
| Keep clear (module SD holder) | x 33–51, y 55.5–83.8: nothing taller than 1 mm |
| J1 USB-C | bottom edge, left (around x 12) |
| J5 jack | bottom edge, right (around x 38) |
| SW1, SW2 | left edge, around y 45 and y 60 |
| Charger, gauge, DAC | anywhere else under the module; DAC near the jack |

- **Antenna:** Raspberry Pi asks for the Pico 2 W to sit at a board edge with a 14 × 9 mm cut-out
  under its antenna, and no metal around it. The top strip is beyond the screen module, so nothing
  covers it; keep the case plastic there.
- **Nothing under the Pico** on our board (except the cut-out). Its micro-USB overhangs the left edge
  slightly, so the case gets a slot there for programming.
- **2 layers, 1.6 mm:** top = parts and signals, bottom = mostly solid ground. No parts on the bottom
  (the battery sticks there with foam tape). No test pads or vias under the battery's edges.
- **Module measurements** (from the photo, 7 Oct 2026; confirm with `docs/screen_template_1to1.pdf`),
  back view, mm from the module's top-left corner: holes (2.7, 6.9), (47.3, 6.9), (2.7, 83.0),
  (47.3, 83.0); J3 pin 1 (6.0, 2.0); J4 pin 1 (21.19, 82.9); SD holder x 0–18, y 32.5–60.8.
  Board position = (1 + 50 − x, 23 + y).

## Routing rules

- Power tracks (`VBUS`, `VSYS`, `VBAT`, `3V3`) **0.5 mm** or wider; signals 0.25 mm.
- Bottom layer: one solid `GND` pour; top layer: `GND` pour around the parts. Stitch them with vias
  along the edges, **never inside the antenna keep-out**.
- Charger capacitors right next to their pins. The 4.7 kΩ / 100 kΩ pull-ups can be anywhere.
- DAC near the jack, with its own capacitors next to its pins; keep its outputs away from the Pico.
- JLCPCB 2-layer rules: 0.127 mm track/space minimum, 0.3 mm vias.

## Bring-up plan

1. Solder the board **without the Pico and screen**. USB-C from a USB power meter: check `VSYS` is
   about 4.4 V. Plug in the battery (polarity!) and check it charges (`CHG_N` low).
2. Solder the Pico. Switch SW1 on: the Pico's 3V3 pin reads 3.3 V. Switch off: 0 V.
3. Plug the Pico's micro-USB into the laptop (USB-C unplugged), flash `pod.uf2`.
4. Plug in the screen module: home screen. Then touch, DAC, SD, Bluetooth, battery percentage.

## Enclosure (after the PCB)

1. Import the board's 3D model (EasyEDA → Export → 3D file / STEP), the screen module and the battery
   into Fusion 360.
2. Front bezel holds the module's glass; back shell holds the board with the battery underneath
   (leave ~0.5 mm around the cell for swelling); four M2 screws or snap fits.
3. Openings: USB-C and jack (bottom), SW1 and SW2 (left side), micro-USB (left side, top),
   microSD slot (right side, at the height of the module's SD holder).
4. Plastic only around the Pico's antenna (top-right corner): no metal paint or inserts.

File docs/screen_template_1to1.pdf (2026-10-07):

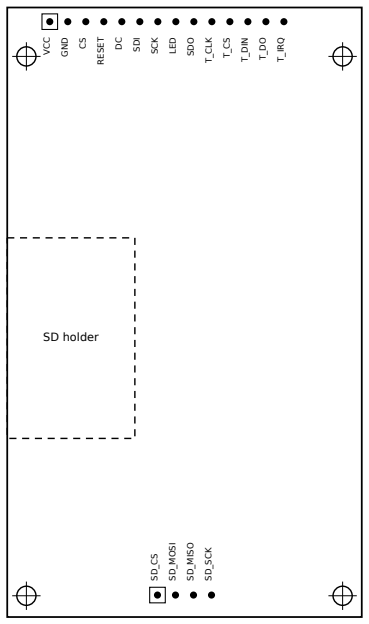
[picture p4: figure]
VCC; GND; RESET; SDI; SCK; LED; SDO; T_CLK; T_DIN; T_IRQ; SD_MOSI; SD_MISO; SD_SCK; SD holder

This bar must measure exactly 50 mm

86 mm

## Pod — screen module check template (1:1)

Print at 100% / Actual size (no 'fit to page'). Check the 50 mm bar with a ruler.
Cut out the rectangle. With the module's back facing you (like your photo),
press the paper on so the 14 header pins poke through the dots (pin 1 = VCC, square).
Then check: do the 4 hole marks and 4 SD pads line up? Note anything off, and by how many mm.

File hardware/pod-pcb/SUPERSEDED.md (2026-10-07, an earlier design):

# Superseded

This KiCad skeleton was for the bare RP2350A + RM2 version of Rev A. On 7 Oct 2026 the board
switched to a soldered-on Pico 2 W and is drawn in EasyEDA Pro. See `docs/pcb-plan.md` and
`docs/easyeda-guide.md`.

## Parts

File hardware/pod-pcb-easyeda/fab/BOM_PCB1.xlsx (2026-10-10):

No. | Quantity | Comment | Designator | Footprint | Value | Manufacturer Part | Manufacturer | Supplier Part | Supplier
1 | 1 | 4.7uF | C1 | C0603 | 4.7uF | CL10A475KO8NNNC | SAMSUNG(三星) | C19666 | LCSC
2 | 6 | 10uF | C2,C3,C4,C8,C9,C13 | C1206 | 10uF | CL31A106KBHNNNE | SAMSUNG(三星) | C13585 | LCSC
3 | 2 | 2.2uF | C5,C6 | C0603 | 2.2uF | CL10A225KO8NNNC | SAMSUNG(三星) | C23630 | LCSC
4 | 2 | 1uF | C7,C14 | C0805 | 1uF | CL21B105KBFNNNE | SAMSUNG(三星) | C28323 | LCSC
5 | 4 | 100nF | C10,C11,C12,C17 | C0402 | 100nF | CL05B104KO5NNNC | SAMSUNG(三星) | C1525 | LCSC
6 | 2 | 2.2nF | C15,C16 | C0805 | 2.2nF | CL21C222JBFNNNE | SAMSUNG(三星) | C28260 | LCSC
7 | 1 | S2B-PH-SM4-TB(LF)(SN) | CN1 | CONN-SMD_P2.00_S2B-PH-SM4-TB-LF-SN |  | S2B-PH-SM4-TB(LF)(SN) | JST | C295747 | LCSC
8 | 1 | PJ-342 | CN2 | AUDIO-SMD_PJ-342_C668606 |  | PJ-342 | SHOU HAN(首韩) | C668606 | LCSC
9 | 1 | GZ1608D601TF | L1 | L0603 |  | GZ1608D601TF | Sunlord(顺络) | C1002 | LCSC
10 | 2 | 5.1kΩ | R1,R2 | R0402 | 5.1kΩ | 0402WGF5101TCE | UNI-ROYAL(厚声) | C25905 | LCSC
11 | 1 | 1.8kΩ | R3 | R0603 | 1.8kΩ | 0603WAF1801T5E | UNI-ROYAL(厚声) | C4177 | LCSC
12 | 1 | 3kΩ | R4 | R0805 | 3kΩ | 0805W8F3001T5E | UNI-ROYAL(厚声) | C17661 | LCSC
13 | 1 | 1.2kΩ | R5 | R0603 | 1.2kΩ | 0603WAF1201T5E | UNI-ROYAL(厚声) | C22765 | LCSC
14 | 2 | 100kΩ | R6,R7 | R0805 | 100kΩ | 0805W8F1003T5E | UNI-ROYAL(厚声) | C149504 | LCSC
15 | 3 | 10kΩ | R10,R11,R16 | R0603 | 10kΩ | 0603WAF1002T5E | UNI-ROYAL(厚声) | C25804 | LCSC
16 | 3 | 4.7kΩ | R12,R13,R17 | R0402 | 4.7kΩ | 0402WGF4701TCE | UNI-ROYAL(厚声) | C25900 | LCSC
17 | 2 | 470Ω | R14,R15 | R0603 | 470Ω | 0603WAF4700T5E | UNI-ROYAL(厚声) | C23179 | LCSC
18 | 1 | MSK12C02-HB | SW1 | SW-TH_MSK12C02-HB-1 |  | MSK12C02-HB | SHOU HAN(首韩) | C431541 | LCSC
19 | 1 | KH-3635-CAJ | SW2 | SW-SMD_KH-3635-CAJ |  | KH-3635-CAJ | kinghelm(金航标) | C530670 | LCSC
20 | 1 | BQ24074RGTR | U1 | QFN-16_L3.0-W3.0-P0.50-TL-EP1.7 |  | BQ24074RGTR | TI(德州仪器) | C54313 | LCSC
21 | 1 | PCM5102APWR | U2 | TSSOP-20_L6.5-W4.4-P0.65-LS6.4-BL |  | PCM5102APWR | TI(德州仪器) | C107671 | LCSC
22 | 1 | MAX17048G+T10 | U3 | TDFN-8_L2.0-W2.0-P0.50-BL-EP1.2 |  | MAX17048G+T10 | ADI(亚德诺)/MAXIM(美信) | C2682616 | LCSC
23 | 1 | TYPE-C-31-M-12 | USBC1 | USB-C_SMD-TYPE-C-31-M-12_1 |  | TYPE-C-31-M-12 | 韩国韩荣 | C165948 | LCSC

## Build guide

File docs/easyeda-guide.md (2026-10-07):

---
pagetitle: Pod PCB in EasyEDA Pro — beginner guide
---

# Pod PCB in EasyEDA Pro — beginner guide

This guide takes you from a blank EasyEDA account to a finished, reviewed **Power sheet**, then
shows how the rest of the board follows. Every value and connection comes from `docs/pcb-plan.md`
(the spec). This guide explains how to draw it, click by click.

**How we work together:** you draw one sheet, export it as a PDF, and send it to me. I check every
connection against the spec, and you fix anything I find before starting the next sheet. Fixing a
mistake in the schematic takes a minute. After the boards are made, the same mistake means ordering
them again.

> Menu names below come from EasyEDA Pro's own documentation. EasyEDA updates its menus from time
> to time. If a name differs slightly, look for the nearest match. Every menu item also shows its
> keyboard shortcut on the right, so check there instead of memorising shortcuts from this guide.

---

## Part A — The ideas you need first (5 minutes)

| Word | What it means |
|---|---|
| **Schematic** | The circuit drawing: which pin connects to which. No sizes or positions, just connections. |
| **PCB** | The physical board: where each part sits and where the copper tracks run. EasyEDA builds it from the schematic. |
| **Symbol** | How a part looks in the schematic (a box with named pins). |
| **Footprint** | The copper pads the part is soldered onto on the PCB. Every symbol is linked to one. |
| **Net** | One electrical connection. Every pin on the same net is joined by copper. |
| **Net label** | A name written on a wire, for example `VBAT`. Two wires with the same label are connected even with no line drawn between them, which keeps the drawing tidy. |
| **Net flag** | A ground or power symbol. Every GND flag is the same `GND` net. |
| **Designator** | The part's ID: R1, C3, U2. |
| **LCSC number** | The stock number JLCPCB uses to assemble the part, for example `C12345`. Parts from EasyEDA's library already carry one. |
| **Basic / Extended part** | JLCPCB keeps *Basic* parts loaded on its machines, so they cost nothing extra. Each *Extended* part adds about $3 to the order. Use Basic for resistors and capacitors. |
| **Decoupling capacitor** | A small capacitor from a chip's power pin to GND that smooths its supply. "C1 10 µF to GND" means one capacitor pin on the net and the other pin on GND. |
| **Pull-up resistor** | A resistor from a signal to 3V3, so the signal reads high unless something pulls it low. |
| **ERC / DRC** | Automatic checks: ERC finds schematic mistakes (an unconnected pin, say) and DRC finds board mistakes (tracks too close). |

**The one rule that matters most:** two points connect only when a wire *ends exactly on a pin*
(the pin end shows a dot or highlights), or when both carry the same net name. A wire that only
crosses a pin is not connected.

---

## Part B — Set up (10 minutes)

### B1. Open EasyEDA Pro

1. Go to **pro.easyeda.com** and sign in. A JLCPCB or LCSC account works here, and you'll use the
   same account to order.
2. Use **EasyEDA Pro**, not "Std Edition". Pro supports multi-page schematics and imports KiCad
   files. If the editor asks you to choose a mode, pick the **online / cloud** mode, so your
   project saves to your account.
3. Use a laptop with a mouse, not a touchpad, in Chrome or Edge.

### B2. Create the project

1. **File → New → Project** (or **New Project** on the start page).
2. Name it **Pod Rev A**, leave the rest, and click **Save**.
3. The left panel shows the project tree: a **Board**, containing a **Schematic** and a **PCB**.
   The Schematic can hold several **pages**.

### B3. Make the 4 pages

1. In the left panel, right-click the schematic → **New Schematic** / **New Page** (EasyEDA calls
   them "schematic pages"). Make 4 pages in total.
2. Right-click each page → **Rename**: `1 Power`, `2 Pico`, `3 Audio`, `4 Screen`.
3. All four pages belong to **one** schematic, so a net named `3V3` on page 1 is the same net as
   `3V3` on page 2. We'll confirm this later when the PCB shows every part linked up.

### B4. Learn the editor (try each of these once on a blank page)

| What | How |
|---|---|
| Zoom | mouse wheel |
| Move the view | hold the right mouse button and drag (or the middle button) |
| Select | left-click; drag a box to select several |
| Move a part | drag it, or select it and use the arrow keys |
| Rotate while placing or moving | **Space** (or **R**; check the menu) |
| Cancel the current tool | **Esc** or a right-click |
| Undo / redo | **Ctrl+Z** / **Ctrl+Y** |
| Delete | select → **Delete** |
| Save | **Ctrl+S** (do this often) |
| Properties | select something; the **right-hand panel** shows its name, value, designator, footprint and LCSC number |

**Bottom panel:** the **Library** (part search) and the check results open here. You can drag the
panel taller.

---

## Part C — Placing parts and drawing connections

Practise each step once on a page, then delete everything before starting the real drawing.

### C1. Find and place a part

1. Open the library: **Place → Devices** (or the **Library** tab in the bottom panel).
2. In the search box, type the **part number (MPN)**, for example `BQ24074RGTR`, and press Enter.
3. Click a result. EasyEDA shows the symbol, the footprint, the LCSC number, stock, and whether
   it's **Basic** or **Extended**. Check:
   - the **package** matches the spec (BQ24074 → VQFN-16), and
   - JLCPCB has **stock**: a Basic or Extended part with a JLCPCB number and stock above zero.
4. Click **Place**, move the mouse to the page, and left-click to drop it. Press **Esc** to stop
   placing more copies.

**Resistors and capacitors:** don't place a generic resistor and type in its value; it would have
no LCSC number. Search the exact value and size instead:

- `1.8k 0402` → pick a **Basic** 1 % 0402 result.
- `10uF 0603` → pick a Basic 0603 capacitor rated for **10 V or more**.

Once you have one 5.1 kΩ resistor placed, **copy and paste** it (Ctrl+C, Ctrl+V) for the second.
The copy keeps the LCSC number, and EasyEDA gives it a new designator.

**Sizes in this design:** resistors 0402; 100 nF and 1 µF capacitors 0402; 4.7 µF and 10 µF
capacitors 0603; 22 µF capacitors 0805.

### C2. Draw a wire

1. **Place → Wire**. The shortcut is shown next to it, usually **W** or **Alt+W**.
2. Click on a pin's **end point** to start, click to add corners, and click on the other pin's end
   to finish. Right-click to stop.
3. Check that each wire end shows the connection marker. A wire end lying near a pin, but not on
   it, is a classic beginner mistake. ERC will catch it, but it's quicker to look as you go.

### C3. Name a wire with a net label (the tidy way)

Instead of drawing long wires across the page, draw a **short stub** from the pin and put a label
on it:

1. Draw a short wire (2–3 grid squares) out from the pin.
2. **Place → Net Label**. Press **Tab** before clicking to type the name, for example `VBUS`.
3. Click on the stub wire to drop the label. The label's corner must sit **on the wire**.
4. Do the same at the other end with the **exact same name**. They are now connected.

Names must match **exactly**, including capitals: `VBAT` ≠ `Vbat`. Use only the names from the
spec.

### C4. Ground and power symbols

- **GND:** **Place → Net Flag** → choose **GND** and put it at the end of a short stub. Each GND
  flag joins the `GND` net, so use as many as you like.
- **Power nets** (`3V3`, `VSYS`, `VBAT`, `VBUS`): either use a power net flag and **rename it** to
  the exact net name in the right panel, or simply use a **net label**. Both work; pick one style
  and use it throughout. Net labels are the safest choice, because a power flag's default name
  (like `VCC`) would quietly create a wrong net.

### C5. Mark unused pins

Pins the spec says to leave open (BQ24074 **TMR**, USB-C **SBU1/SBU2**): **Place → No Connect
Flag** and click the pin end. This tells ERC the pin was left open on purpose.

### C6. The exposed pad

Several chips (BQ24074, MAX17048) have a metal pad underneath, shown as an extra pin
named **EP**, **PAD**, **PowerPAD** or **thermal pad**. Connect it to **GND** unless the spec says
otherwise.

---

## Part D — Drawing Sheet 1: Power, step by step

Open page **1 Power**. Draw it in four groups from left to right, as the power flows:
**USB-C → charger and battery → power switch → fuel gauge.** Leave space between the
groups.

Tick each line as you draw it. When a chip's pin name in EasyEDA differs from the spec, match by
the pin's **function** in the chip's datasheet (click the part → the datasheet link in the right
panel) and tell me when you send the PDF.

### D1. USB-C socket (J1)

Search `TYPE-C-31-M-12` (or `USB4105-GF-A`). Choose a **16-pin** version, not a 6-pin
charge-only socket and not a 24-pin socket.

Some symbols join pins with the same job into one pin, labelled for example `A4B9`, or simply
`VBUS`. That's fine: connect each pin that exists.

- [ ] All **VBUS** pins (A4, A9, B4, B9) → label `VBUS`
- [ ] All **GND** pins (A1, A12, B1, B12) and the **shell / SHIELD / EH** pins → `GND`
- [ ] **CC1** (A5) → R1 **5.1 kΩ** → GND
- [ ] **CC2** (B5) → R2 **5.1 kΩ** → GND (one resistor each; never share one)
- [ ] **D+** (A6, B6), **D−** (A7, B7), **SBU1**, **SBU2** → No Connect flag. The USB-C socket
      only charges; programming goes through the Pico's own micro-USB.

*Why the CC resistors:* a USB-C charger outputs 0 V until it sees 5.1 kΩ on CC. Leaving them out
is the most common USB-C mistake.

### D2. Charger (U2)

Search `BQ24074RGTR` (VQFN-16). Put it in the middle of the page with room around it, because
nine of its pins get a part.

- [ ] **IN** → `VBUS`, and C1 **4.7 µF** from IN to GND
- [ ] **OUT** → `VSYS`, and C2 **10 µF** from OUT to GND
- [ ] **BAT** → `VBAT`, and C3 **10 µF** from BAT to GND
- [ ] **ISET** → R4 **1.8 kΩ** → GND (sets about 0.5 A charging)
- [ ] **ILIM** → R5 **1.2 kΩ** → GND (sets the 1.34 A input limit)
- [ ] **ITERM** → R6 **3.0 kΩ** → GND (charging stops at 50 mA)
- [ ] **TS** → R3 **10 kΩ** → GND
- [ ] **EN2** → `VBUS`
- [ ] **EN1** → GND
- [ ] **CE** → GND
- [ ] **SYSOFF** → GND
- [ ] **TMR** → No Connect flag
- [ ] **CHG** → label `CHG_N`, and R7 **100 kΩ** from `CHG_N` to `3V3`
- [ ] **PGOOD** → label `PGOOD_N`, and R8 **100 kΩ** from `PGOOD_N` to `3V3`
- [ ] **VSS** and the exposed pad → GND

**How to draw a "pull-up":** put the resistor vertically. Its top pin goes to a stub labelled `3V3`,
and its bottom pin goes to a stub labelled `CHG_N`. A third stub labelled `CHG_N` sits on the chip
pin. All three are now correctly joined, with no long wires.

### D3. Battery connector (J2)

Search `S2B-PH-SM4-TB` (JST-PH, 2 pins, side-entry SMD).

- [ ] Pin 1 → `VBAT`
- [ ] Pin 2 → `GND`

On the page, put a text note next to it: **"check battery polarity"**: **Place → Text**. LiPo
cells come wired either way round. Plugging in a reversed one destroys the charger.

### D4. Power/hold switch (SW1)

Search `MSK-12C02`. It has three main pins: one in the middle (common) and one at each side, plus
mounting pins.

- [ ] **Middle (common)** → label `3V3_EN`
- [ ] **One side** (OFF) → `GND`
- [ ] **Other side** (ON) → No Connect flag. The Pico holds 3V3_EN high by itself, so "on" just
      means "not grounded".
- [ ] Mounting/shell pins → GND (or No Connect)

### D5. Fuel gauge (U3)

Search `MAX17048G+T10` (TDFN-8).

- [ ] **VDD** → `VBAT`, and C4 **1 µF** from VDD to GND
- [ ] **CELL** → `VBAT`
- [ ] **GND**, **CTG**, **QSTRT** and the exposed pad → GND
- [ ] **SDA** → label `I2C_SDA`, with R9 **4.7 kΩ** to `3V3`
- [ ] **SCL** → label `I2C_SCL`, with R10 **4.7 kΩ** to `3V3`
- [ ] **ALRT** → label `GAUGE_ALRT_N`, with R11 **10 kΩ** to `3V3`

Labels like `CHG_N`, `PGOOD_N`, `I2C_SDA`, `I2C_SCL`, `GAUGE_ALRT_N`, `VSYS`, `3V3` and `3V3_EN`
go nowhere on this page. That's expected: they connect to the Pico on page 2.

### D6. Tidy up

1. **Designators:** if numbers are messy or duplicated, run **Design → Annotate** (the wording
   might be "Annotate Designator"). Then compare the resistors and capacitors with the spec. Matching the
   spec's numbers makes my review faster, but it isn't essential: I check by connection.
2. **Values visible:** every resistor and capacitor should show its value on the page. If one
   doesn't, select it and switch on the value in the right panel.
3. **Text notes:** add a title at the top of the page: **Place → Text** → "Power: USB-C,
   charger, battery, power switch, fuel gauge".

### D7. Check it

1. **Design → Check DRC** (for a schematic this runs the electrical check, ERC). Results show in
   the bottom panel. Click a result to jump to it.
2. What to fix, and what to leave:

| Message (roughly) | Meaning | Action |
|---|---|---|
| Pin not connected | a pin has nothing on it | connect it, or add a No Connect flag if the spec says open |
| Net has only one pin / single-pin net | a label is spelled differently from its partner, or a wire end missed a pin | fix the spelling or the wire. Exception: labels that continue on page 2 (`CHG_N`, `I2C_SDA`, …) will show this until page 2 exists, so leave those |
| Duplicate designator | two parts share a name | run Annotate |
| Part has no footprint | rare with library parts | tell me which part |

3. **Ctrl+S.**

### D8. Send it to me

1. **Export → PDF/Image** (in some versions under **File → Export**). Choose **PDF**, select
   **all pages** (or only page 1 for now), and use **colour** if offered.
2. Also export the **BOM**: **Export → Bill of Materials (BOM)**, as a CSV or Excel file. This
   lets me check every package and LCSC number.
3. Send both here. I'll reply with a checklist of anything to change.

---

## Part D2 — Drawing Sheet 2: the Pico 2 W

The board carries your own Pico 2 W, soldered on. Its chip, flash, radio and 3.3 V regulator are
already on the Pico, so this page is just the Pico and a label on each pin.

**First, tidy the pages:** right-click **2. MCU** → **Rename** → `2. Pico`. Right-click
**3. Radio** → **Delete**. Rename the last two to `3. Audio` and `4. Screen`.

### P1. Place the Pico (as two 20-pin headers)

EasyEDA's Pico parts only have flat surface pads, and your Pico has header pins that need holes.
So the Pico is drawn as **two straight 1×20, 2.54 mm through-hole headers**:

1. In the library search box (**LCSC Electronics** tab), type **`C50981`**: BOOMELE 2.54-1*20P,
   a straight 1×20 through-hole pin header. Place it twice and name them **J6** and **J7**.
2. Set **Add into BOM → No** on both (they're only holes for the Pico's own pins).
3. Add a text note: "J6 = Pico pins 1–20, J7 = Pico pins 21–40".
4. **J6 pin n = Pico pin n. J7 pin n = Pico pin 20 + n.** Label them from the tables below using
   the Pico pin numbers.
5. On the board: J6 pin 1 at (1.87, 20.39) running right; J7 pin 1 at (50.13, 2.61) running left
   (rows 17.78 mm apart, matching the Pico).

### P2. Power pins

- [ ] **VSYS** (pin 39) → `VSYS`
- [ ] **VBUS** (pin 40) → `VBUS`
- [ ] **3V3** (pin 36, "3V3(OUT)") → `3V3`, with a **10 µF 0603** capacitor from `3V3` to GND
- [ ] **3V3_EN** (pin 37) → `3V3_EN`
- [ ] **Every GND pin** (3, 8, 13, 18, 23, 28, 38) and **AGND** (33) → `GND`

### P3. GPIO labels

One short stub and label on each pin. The names must match exactly, because they join the Pico to
the other pages.

| Pin | Pico | Label | | Pin | Pico | Label |
|---|---|---|---|---|---|---|
| 2 | GP1 | `HP_DET` | | 21 | GP16 | `LCD_DC` |
| 4 | GP2 | `GAUGE_ALRT_N` | | 22 | GP17 | `LCD_CS` |
| 6 | GP4 | `I2C_SDA` | | 24 | GP18 | `SPI0_SCK` |
| 7 | GP5 | `I2C_SCL` | | 25 | GP19 | `SPI0_MOSI` |
| 9 | GP6 | `BTN_PLAY_N` | | 26 | GP20 | `SPI0_MISO` |
| 10 | GP7 | `SD_CS` | | 27 | GP21 | `LCD_RST` |
| 12 | GP9 | `I2S_DIN` | | 29 | GP22 | `TOUCH_CS` |
| 14 | GP10 | `I2S_BCK` | | 31 | GP26 | `TOUCH_IRQ` |
| 15 | GP11 | `I2S_LRCK` | | 32 | GP27 | `PGOOD_N` |
| 16 | GP12 | `DAC_XSMT` | | 34 | GP28 | `CHG_N` |
| 17 | GP13 | `LCD_LED` | | | | |

These are the same pins your breadboard uses, so the firmware runs unchanged.

### P4. Unused pins

- [ ] No Connect flag on **GP0** (1), **GP3** (5), **GP8** (11), **GP14** (19), **GP15** (20),
      **RUN** (30), **ADC_VREF** (35), and the 3 debug pins (SWCLK, GND, SWDIO) if the symbol
      has them.

### P5. Check and send

1. **Design → Annotate**, then **Design → Check DRC**. The "single pin" warnings for `CHG_N`,
   `I2C_SDA` and so on from the Power page should now be gone, because both ends exist.
2. **Back on the Power page**, make the two changes from the new plan, if you haven't yet:
   - delete the 3.3 V regulator group (TPS63802, inductor, its capacitors and the 56k/10k/100k
     resistors) and the USBLC6-2SC6;
   - USB-C data pins and SBU pins → No Connect; switch common → `3V3_EN`, one side `GND`, the
     other side No Connect.
3. Send the PDF of both pages, plus the **BOM**.

---

## Part D3 — Drawing Sheet 3: Audio, step by step

Open page **3 Audio**. It has two groups: the **DAC** (it turns the Pico's digital music into an
analog signal) and the **headphone jack**.

**Parts on this page** (all 0402 Basic unless noted):

| Value | Count | Notes |
|---|---|---|
| 100 nF | 3 | |
| 10 µF **0603** | 3 | rated 10 V or more |
| 2.2 µF | 2 | rated 10 V or more |
| 1 µF | 1 | |
| 2.2 nF | 2 | type C0G / NP0 |
| 470 Ω | 2 | |
| 10 kΩ | 1 | |
| 4.7 kΩ | 1 | |
| Ferrite bead 600 Ω @ 100 MHz, **0603** | 1 | search **`C1002`** (Sunlord GZ1608D601TF, Basic) |

### A1. The DAC (U8)

Search `PCM5102APWR` (TSSOP-20). Its pins are numbered 1–20; the names below match the symbol.

**Power**

- [ ] **CPVDD** (1) → `3V3`, with **100 nF** and **10 µF** to GND
- [ ] **CPGND** (3) → GND
- [ ] **CAPP** (2) ↔ **CAPM** (4): one **2.2 µF** capacitor *between these two pins* (neither end to GND)
- [ ] **VNEG** (5) → **2.2 µF** → GND
- [ ] **AVDD** (8) → net `AVDD_DAC`. Then the **ferrite bead** from `3V3` to `AVDD_DAC`, and
      **10 µF** + **100 nF** from `AVDD_DAC` to GND. *(The bead keeps digital noise out of the
      analog supply.)*
- [ ] **AGND** (9) → GND
- [ ] **DVDD** (20) → `3V3`, with **100 nF** and **10 µF** to GND
- [ ] **DGND** (19) → GND
- [ ] **LDOO** (18) → **1 µF** → GND (nothing else on this pin)

**Digital inputs from the Pico**

- [ ] **BCK** (13) → `I2S_BCK`
- [ ] **DIN** (14) → `I2S_DIN`
- [ ] **LRCK** (15) → `I2S_LRCK`
- [ ] **SCK** (12) → GND *(the DAC makes its own clock, exactly as on your breadboard)*
- [ ] **XSMT** (17) → `DAC_XSMT`, and **10 kΩ** from `DAC_XSMT` to GND *(muted until the
      firmware un-mutes it: no pop at power-on)*

**Settings pins**

- [ ] **DEMP** (10), **FLT** (11), **FMT** (16) → GND

**Outputs**

- [ ] **OUTL** (6) → **470 Ω** → label `HP_L`, and **2.2 nF** from `HP_L` to GND
- [ ] **OUTR** (7) → **470 Ω** → label `HP_R`, and **2.2 nF** from `HP_R` to GND

### A2. The headphone jack (J5)

Search **`C668606`** (SHOU HAN **PJ-342**). Pins, from its datasheet:

- [ ] Pins **5** and **2** (ground contacts) → GND
- [ ] Pin **6** (left spring) → `HP_L`
- [ ] Pin **3** (right spring) → `HP_R`
- [ ] Pin **7** (switch contact under spring 6) → **4.7 kΩ** → `HP_DET`
- [ ] Pin **4** (switch contact under spring 3) → No Connect flag

### A3. Check and send

1. **Design → Annotate**, then **Design → Check DRC**. `I2S_BCK`, `I2S_DIN`, `I2S_LRCK`,
   `DAC_XSMT` and `HP_DET` now have both ends, so their warnings should go.
2. Send the PDF (all pages) and the **BOM**.

---

## Part D4 — Drawing Sheet 4: Screen, step by step

Open page **4 Screen**. This page has the two sockets the red screen module plugs into, and the
play/pause button. The mounting holes are added later, on the board layout.

### S1. Main screen socket (J3, 14 pins)

Search **`C5307340`** (ZHOURI **PM2.54-1\*14**: 1×14 female header, 2.54 mm, 8.5 mm tall). Name it
**J3**. Pin 1 is the module's **VCC** pin, the first one printed on the module's header.

| J3 pin | Module pin | Net |
|---|---|---|
| 1 | VCC | `3V3` |
| 2 | GND | `GND` |
| 3 | CS | `LCD_CS` |
| 4 | RESET | `LCD_RST` |
| 5 | DC | `LCD_DC` |
| 6 | SDI (MOSI) | `SPI0_MOSI` |
| 7 | SCK | `SPI0_SCK` |
| 8 | LED | `LCD_LED` |
| 9 | SDO (MISO) | **No Connect** (the screen doesn't let go of this line, so it stays off the shared bus) |
| 10 | T_CLK | `SPI0_SCK` |
| 11 | T_CS | `TOUCH_CS` |
| 12 | T_DIN | `SPI0_MOSI` |
| 13 | T_DO | `SPI0_MISO` |
| 14 | T_IRQ | `TOUCH_IRQ` |

Pins 7 and 10 share `SPI0_SCK`, and pins 6 and 12 share `SPI0_MOSI`. That's intended: the screen,
touch and SD card take turns on one bus, exactly as on your breadboard.

### S2. SD card socket (J4, 4 pins)

Search **`C2897367`** (HCTL **PM254-1-04-Z-8.5**: 1×4 female header, 2.54 mm, 8.5 mm tall). Name it
**J4**. Check the order printed next to the SD pins on **your** module; on the MSP2807 it is:

| J4 pin | Module pin | Net |
|---|---|---|
| 1 | SD_CS | `SD_CS` |
| 2 | SD_MOSI | `SPI0_MOSI` |
| 3 | SD_MISO | `SPI0_MISO` |
| 4 | SD_SCK | `SPI0_SCK` |

If your module prints them in a different order, follow the module and tell me.

### S3. Play/pause button (SW2)

Search **`C530670`** (Kinghelm **KH-3635-CAJ**: a small side-push button that sits on the board edge;
if it's out of stock, `C502303` works too).

- [ ] One side of the button → `BTN_PLAY_N`
- [ ] Other side → `GND`
- [ ] **100 nF** (0402) from `BTN_PLAY_N` to GND, which smooths out contact bounce
- [ ] If the symbol has 4 pins, they're joined in pairs: wire one pair to each side (check the
      datasheet drawing, or send me a screenshot)

### S4. Check and send

1. **Design → Annotate**, then **Design → Check DRC**. With all four pages drawn, every label now
   has both ends, so the "single pin net" warnings should be gone. Send me a screenshot of any
   that remain.
2. Send the **PDF of all four pages** and the **BOM**. After that review we move to the board
   layout.

---

## Part G — From schematic to board (after all four pages are reviewed)

### G1. Make the PCB

1. **Design → Update/Convert Schematic to PCB**. A dialog lists every part and net. Click
   **Apply Changes**.
2. The PCB opens with every part piled to one side, joined by thin straight lines (the
   **ratsnest**): the connections still to be made.
3. **Check:** the Pico should have ratsnest lines to parts on all the other pages. That confirms
   the pages are linked.

### G2. Board settings

1. **Layers:** **Tools → Layer Manager** → **2 copper layers**, thickness **1.6 mm**.
2. **Design rules:** **Design → Design Rule**: track width 0.25 mm for signals, **0.5 mm** for power
   nets (`VBUS`, `VSYS`, `VBAT`, `3V3`, `GND`), clearance 0.2 mm, vias 0.3 mm drill / 0.6 mm pad.
3. **Units:** mm.

### G3. Draw the outline (with the antenna notch)

The board is 52 × 109 mm with a 9 × 14 mm notch in the right edge, under the Pico's antenna. Draw
it as one shape: select the **Board Outline** layer, **Place → Board Outline** → **polygon**, and
click these corners in order (or type them in the right panel):

(0, 0) → (52, 0) → (52, 4.5) → (42.5, 4.5) → (42.5, 18.5) → (52, 18.5) → (52, 109) → (0, 109) → back to (0, 0)

If EasyEDA's Y axis counts **upward**, use negative Y values instead (0, −4.5 and so on). Either way,
the outline must look like the drawing in the spec, with the notch near the top-right corner.

### G4. Place the fixed parts by typing coordinates

EasyEDA positions a part by its **centre**. Set units to **mm**, then check the Y direction: move the
mouse down from the top-left corner. If Y goes negative, add a minus sign to every Y below.

| Part | Centre X | Centre Y | Orientation |
|---|---|---|---|
| **J6** (Pico pins 1–20) | 26.00 | 20.39 | pins left–right, square pad (pin 1) at the **left** |
| **J7** (Pico pins 21–40) | 26.00 | 2.61 | pins left–right, square pad at the **right** |
| **J3** (14-pin screen socket) | 28.49 | 25.00 | pins left–right, square pad at the **right** |
| **J4** (4-pin SD socket) | 26.00 | 105.90 | pins left–right, square pad at the **right** |
| Holes (**Place → Hole**, 2.7 mm) | 3.70 / 48.30 | 29.90 / 106.00 | four corners |

**Check:** hovering over each square pad should read J6 (1.87, 20.39), J7 (50.13, 2.61), J3 (45.0, 25.0),
J4 (29.8, 105.9). If one is off, rotate the part 180° and re-enter its centre.

**If EasyEDA's Y axis counts upward** (it does in EasyEDA Pro: the Y ruler goes up from 0), don't
just type these Y values, or the whole board comes out mirrored top-to-bottom. Use **Y = 109 − y**
instead, with the board drawn from (0, 0) at the bottom-left up to (52, 109):

| Item | Y-up values |
|---|---|
| Outline | (0,0) → (52,0) → (52,90.5) → (42.5,90.5) → (42.5,104.5) → (52,104.5) → (52,109) → (0,109) |
| J6 centre | (26.00, 88.61); pin 1 at (1.87, 88.61), square pad on the left |
| J7 centre | (26.00, 106.39); pin 1 at (50.13, 106.39), square pad on the right |
| J3 centre | (28.49, 84.00); pin 1 at (45.0, 84.0), square pad on the right |
| J4 centre | (26.00, 3.10); pin 1 at (29.8, 3.1), square pad on the right |
| Holes | (3.7, 79.1), (48.3, 79.1), (3.7, 3.0), (48.3, 3.0) |
| Edge parts | USB-C and jack on the bottom edge (y ≈ 0); SW1 y ≈ 64, SW2 y ≈ 49, battery connector y ≈ 24 on the left edge |

Edge parts (roughly): USB-C bottom edge at x ≈ 12.5, opening down; jack bottom edge at x ≈ 38, opening
down; SW1 left edge at y ≈ 45; SW2 left edge at y ≈ 60, button facing out; battery connector left edge
at y ≈ 85, opening facing out.

Then print `docs/screen_template_1to1.pdf` and lay it against the module to double-check the screen
positions, and look at **View → 3D**.

### G5. Keep-outs

- **Antenna:** no copper on either layer within about 2 mm of the notch: **Place → Keep-out Region
  / Prohibited Region**, all layers.
- **Nothing under the Pico** except its own pads.
- **Under the module's SD holder** (x 33–51, y 55.5–83.8): no part taller than 1 mm.
- **Bottom side:** no parts at all; the battery sticks there.

### G6. Place everything else

Charger with its capacitors right next to its pins, gauge next to the battery connector, DAC next
to the jack. Then send me a screenshot **before routing**. Placement decides most of how well the
board works.

### G7. Route, step by step

"Routing" means drawing the copper tracks that replace the thin blue ratsnest lines. When every
blue line is gone and DRC shows no errors, the board is finished. Work in this order: each step
makes the next one easier.

**Two layers:** the **Top** layer holds the parts and most tracks. The **Bottom** layer will be
almost entirely one solid sheet of ground copper. Only use the bottom layer for short hops where two
top tracks would otherwise cross.

### R1. Set the rules (once)

1. **Design → Design Rule** (it may be called *Rule Settings* or *Rules Manager*).
2. **Track width**, default rule: **0.25 mm**. **Clearance**: **0.2 mm**. **Via**: hole **0.3 mm**,
   diameter **0.6 mm**.
3. **Net Class**: create a class named **POWER**, add the nets `VBUS`, `VSYS`, `VBAT`, `3V3` and
   `GND`, and give it a track width of **0.5 mm**. EasyEDA then uses the wider track automatically
   when you route those nets.
4. If you can't find net classes, just type the width in the toolbar or right panel while drawing
   each power track.

### R2. How to draw a track

1. Select the **Top** layer in the layer bar at the bottom of the canvas.
2. **Route → Track** (shortcut usually **W**; it's shown next to the menu item).
3. Click on a pad, click to add corners, and click on the destination pad. Right-click or **Esc**
   to finish. Use **45° corners**, never 90°.
4. **To change layers in the middle of a track:** finish the track, **Place → Via** at that spot,
   switch the layer bar to **Bottom**, and continue from the via. Afterwards, switch back to Top.
5. **Highlight a net:** click any pad, and every pad on that net lights up. Useful to see where a
   track has to go.
6. **Undo** mistakes with Ctrl+Z, or click a track and press Delete.

### R3. Power tracks first (0.5 mm)

Click a pad of each net to highlight it, then draw:

| Net | Route from → to |
|---|---|
| `VBUS` | USB-C VBUS pads → charger IN (U1) and its 4.7 µF → **Pico VBUS** (J1 pin 20). This one runs the length of the board. |
| `VSYS` | charger OUT (U1, both pins) → its 10 µF → **Pico VSYS** (J1 pin 19), also the length of the board. Run it beside `VBUS`. |
| `VBAT` | charger BAT pins (U1) → its 10 µF → battery connector CN1 pin 1 → gauge VDD and CELL (U3) |
| `3V3` | **Pico 3V3** (J1 pin 16) → C4 → screen socket pin 1 (U4) → the DAC area (C8/C11 for CPVDD, C9/C10 for DVDD, the ferrite L1) → the pull-up resistors (R6, R7, R11–R13) |
| `3V3_EN` | SW1 middle pin → Pico pin 37 (J1 pin 17). A signal track (0.25 mm) is fine. |

**Don't route GND at all.** The copper pour in step R6 connects every GND pad.

### R4. Short connections next to the chips

Connect each small capacitor and resistor to the chip pin it sits beside: the charger's ISET/ILIM/
ITERM/TS resistors, the DAC's capacitors (CAPP–CAPM, VNEG, LDOO, AVDD), the USB-C CC resistors, the
2.2 nF and 470 Ω on the audio outputs, and the 4.7 kΩ on the jack. These are all a few millimetres
long.

### R5. Signals (0.25 mm)

What's left are the long signals from the Pico to the parts at the far end:

- **Screen** (`LCD_*`, `SPI0_*`, `TOUCH_*`): Pico → the 14-pin socket U4, which is close by. The
  `SPI0_*` nets also continue to the SD socket U5 at the far end.
- **Audio** (`I2S_BCK`, `I2S_DIN`, `I2S_LRCK`, `DAC_XSMT`, `HP_DET`) and **gauge/charger**
  (`I2C_SDA`, `I2C_SCL`, `GAUGE_ALRT_N`, `CHG_N`, `PGOOD_N`), plus `BTN_PLAY_N`: Pico → the far end.

Run the long ones as a **neat bundle down the middle of the board**, side by side, 0.25 mm wide with
0.25 mm gaps. A single 0.25 mm track fits between two Pico header pins, if you need it.

**Option: let the autorouter do the signals.** After R3 and R4 are done by hand, **Route → Auto
Route** can draw the remaining signals. Tell it to **skip GND** (and keep your existing tracks).
Then send me a screenshot: autorouters sometimes make messy detours that are worth fixing by hand.

### R6. Ground pour (last)

1. Select the **Bottom** layer. **Place → Copper Area** (also called *Copper Pour* or *Polygon
   Pour*), **net GND**, and draw a rectangle around the whole board.
2. Do the same on the **Top** layer, net GND.
3. EasyEDA fills every empty space with ground and connects all the GND pads to it. If it doesn't
   refill automatically, use **Rebuild Copper Areas** (or press **Shift+B**).
4. Add a few **vias** (Place → Via, net GND) around the board, especially near the charger, the DAC
   and the Pico GND pins. They join the top and bottom ground together.
5. **Keep the antenna notch area clear:** place a **Prohibited Region / Keep-out** on both layers,
   covering the notch plus about 2 mm around it, so the pour stays away from the antenna.

### R7. Check

1. **Design → Check DRC** until the list is empty. "Connection Error" means a track is missing;
   "Clearance" means two things are too close.
2. Look at the board in **3D**.
3. Send me a screenshot of the routed board (top and bottom layers), the DRC result, and a PDF
   export. I'll check it before you order.

---

## Part H — Ordering (after the final review)

1. **Export → PCB Fabrication Files (Gerber)**, **Export → Bill of Materials (BOM)**, and
   **Export → Pick and Place File**. Send all three to me for a final check.
2. **Order → PCB Order** sends the design to JLCPCB. Choose **2 layers, 1.6 mm**, 5 boards, and
   switch on **PCB Assembly → top side**.
3. JLCPCB then shows each part on a picture of the board. **Check every chip's pin 1 dot and
   rotation** before paying. Leave out the Pico and the two screen sockets; you solder those
   yourself.

---

## Getting a review

| When | Send |
|---|---|
| after each schematic page | **schematic PDF** (Export → PDF/Image) + **BOM** |
| before routing | screenshot of the placed board, plus the 3D view |
| before ordering | Gerber zip, BOM, pick-and-place file |

Now and then, also save the project into the repo: **File → Export → EasyEDA Pro project
(.epro)** → put it in `hardware/pod-pcb-easyeda/` on GitHub. The board design is then versioned
alongside the firmware.

## When you're stuck

- A part shows no stock: send me the MPN, and I'll find an equivalent.
- A pin name doesn't match the spec: take a screenshot of the symbol and send it.
- Something won't connect: zoom right in. The wire end is usually a grid square away from the pin.
- EasyEDA's own manual: **prodocs.easyeda.com** (search box at the top).

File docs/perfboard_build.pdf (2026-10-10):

# Pod perfboard: solder side

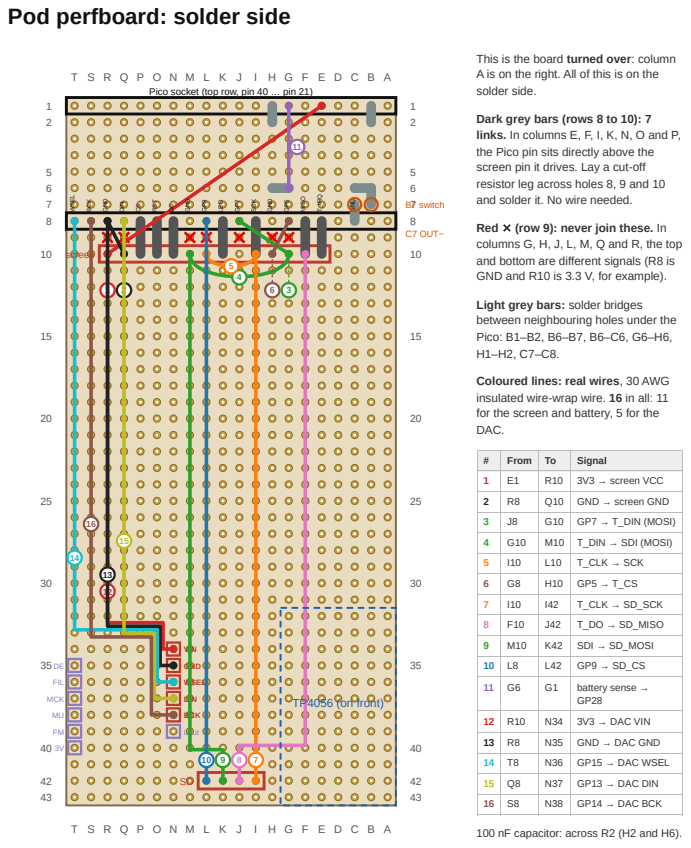
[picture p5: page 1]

This is the board turned over: column
A is on the right. All of this is on the
solder side.

Pico socket (top row, pin 40 … pin 21)

Dark grey bars (rows 8 to 10): 7
links. In columns E, F, I, K, N, O and P,
the Pico pin sits directly above the
screen pin it drives. Lay a cut-off
resistor leg across holes 8, 9 and 10
and solder it. No wire needed.

Red ✕ (row 9): never join these. In
columns G, H, J, L, M, Q and R, the top
and bottom are different signals (R8 is
GND and R10 is 3.3 V, for example).

Light grey bars: solder bridges
between neighbouring holes under the
Pico: B1–B2, B6–B7, B6–C6, G6–H6,

Coloured lines: real wires, 30 AWG
insulated wire-wrap wire. 16 in all: 11
for the screen and battery, 5 for the
DAC.

# | From | To | Signal
1 | E1 | R10 | 3V3 → screen VCC
2 | R8 | Q10 | GND → screen GND
3 | J8 | G10 | GP7 → T_DIN (MOSI)
4 | G10 | M10 | T_DIN → SDI (MOSI)
5 | I10 | L10 | T_CLK → SCK
6 | G8 | H10 | GP5 → T_CS
7 | I10 | I42 | T_CLK → SD_SCK
8 | F10 | J42 | T_DO → SD_MISO
9 | M10 | K42 | SDI → SD_MOSI
10 | L8 | L42 | GP9 → SD_CS

11 | G6 | G1 | battery sense → GP28

12 | R10 | N34 | 3V3 → DAC VIN
13 | R8 | N35 | GND → DAC GND
14 | T8 | N36 | GP15 → DAC WSEL
15 | Q8 | N37 | GP13 → DAC DIN
16 | S8 | N38 | GP14 → DAC BCK

100 nF capacitor: across R2 (H2 and H6).

## Hole-by-hole map

Every hole that gets solder, row by row. Tick each one as you do it. Any hole not listed stays empty.

| Hole | What's in it | Joins to
☐ | B1 | Pico pin 39 (VSYS) | solder bridge to B2
☐ | E1 | Pico pin 36 (3V3) | wire 1 starts here
☐ | G1 | Pico pin 34 (GP28) | wire 11 ends here
☐ | H1 | Pico pin 33 (AGND) | solder bridge to H2
☐ | rest of row 1 | Pico socket pins | socket solder joint only
☐ | B2 | D1, band end | bridge to B1
☐ | H2 | R2 + 100 nF | bridge to H1
☐ | B6 | D1, plain end | bridges to B7 and C6
☐ | C6 | R1 | bridge to B6
☐ | G6 | R1 | bridge to H6; wire 11 starts
☐ | H6 | R2 + 100 nF | bridge to G6
☐ | B7 | red wire from switch | bridge to B6
☐ | C7 | black wire from TP4056 OUT− | bridge to C8
☐ | C8 | Pico pin 3 (GND) | bridge to C7
☐ | E8 | Pico pin 5 (GP3) | LINK to E10
☐ | F8 | Pico pin 6 (GP4) | LINK to F10
☐ | G8 | Pico pin 7 (GP5) | wire 6 starts
☐ | I8 | Pico pin 9 (GP6) | LINK to I10
☐ | J8 | Pico pin 10 (GP7) | wire 3 starts
☐ | K8 | Pico pin 11 (GP8) | LINK to K10
☐ | L8 | Pico pin 12 (GP9) | wire 10 starts
☐ | N8 | Pico pin 14 (GP10) | LINK to N10
☐ | O8 | Pico pin 15 (GP11) | LINK to O10
☐ | P8 | Pico pin 16 (GP12) | LINK to P10
☐ | Q8 | Pico pin 17 (GP13) | wire 15 starts
☐ | R8 | Pico pin 18 (GND) | wires 2 and 13 start
☐ | S8 | Pico pin 19 (GP14) | wire 16 starts
☐ | T8 | Pico pin 20 (GP15) | wire 14 starts
☐ | A8, B8, D8, H8, M8 | Pico socket pins | socket solder joint only
☐ | E9 | link only | part of the E8–E10 link
☐ | F9 | link only | part of the F8–F10 link
| Hole | What's in it | Joins to
☐ | I9 | link only | part of the I8–I10 link
☐ | K9 | link only | part of the K8–K10 link
☐ | N9 | link only | part of the N8–N10 link
☐ | O9 | link only | part of the O8–O10 link
☐ | P9 | link only | part of the P8–P10 link
☐ | other row 9 | empty | never solder G9, H9, J9, L9, M9, Q9, R9
☐ | R10 | screen pin 1 (VCC) | wire 1 ends; wire 12 starts
☐ | Q10 | screen pin 2 (GND) | wire 2 ends
☐ | P10 | screen pin 3 (CS) | LINK from P8
☐ | O10 | screen pin 4 (RESET) | LINK from O8
☐ | N10 | screen pin 5 (DC) | LINK from N8
☐ | M10 | screen pin 6 (SDI) | wires 4 and 9
☐ | L10 | screen pin 7 (SCK) | wire 5 ends
☐ | K10 | screen pin 8 (LED) | LINK from K8
☐ | J10 | screen pin 9 (SDO) | nothing (SDO stays unconnected)
☐ | I10 | screen pin 10 (T_CLK) | LINK from I8; wires 5 and 7
☐ | H10 | screen pin 11 (T_CS) | wire 6 ends
☐ | G10 | screen pin 12 (T_DIN) | wires 3 and 4
☐ | F10 | screen pin 13 (T_DO) | LINK from F8; wire 8 starts
☐ | E10 | screen pin 14 (T_IRQ) | LINK from E8
☐ | L42 | SD pin 1 (SD_CS) | wire 10 ends
☐ | K42 | SD pin 2 (SD_MOSI) | wire 9 ends
☐ | J42 | SD pin 3 (SD_MISO) | wire 8 ends
☐ | I42 | SD pin 4 (SD_SCK) | wire 7 ends
☐ | N34 | DAC pin VIN | wire 12 ends
☐ | N35 | DAC pin GND | wire 13 ends
☐ | N36 | DAC pin WSEL | wire 14 ends
☐ | N37 | DAC pin DIN | wire 15 ends
☐ | N38 | DAC pin BCK | wire 16 ends
☐ | N39 | DAC pin Lout | nothing
☐ | T35– T40
DAC pins DE, FIL,
MCK, MU, FM, 3V

nothing: solder joint only

## Front view: where everything sits

D1 | Pico 2 W

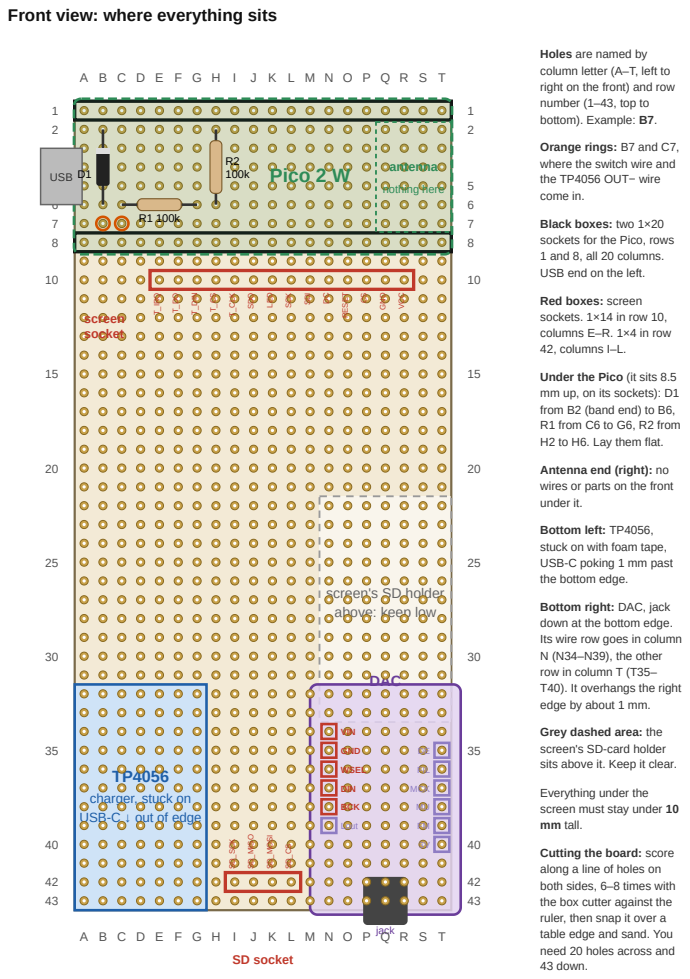
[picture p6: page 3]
DAC; jack; VIN; GND; WSEL; DIN; BCK; Lout; FIL; MCK; USB; antenna; nothing here; VCC; RESET; SDI; SCK; LED; SDO; T_CLK; T_DIN; T_IRQ; SD_MOSI; SD_MISO; SD_SCK; screen socket; SD socket

Holes are named by
column letter (A–T, left to
right on the front) and row
number (1–43, top to
bottom). Example: B7.

Orange rings: B7 and C7,
where the switch wire and
the TP4056 OUT− wire
come in.

Black boxes: two 1×20
sockets for the Pico, rows
1 and 8, all 20 columns.
USB end on the left.

Red boxes: screen
sockets. 1×14 in row 10,
columns E–R. 1×4 in row
42, columns I–L.

Under the Pico (it sits 8.5
mm up, on its sockets): D1
from B2 (band end) to B6,
R1 from C6 to G6, R2 from
H2 to H6. Lay them flat.

Antenna end (right): no
wires or parts on the front
under it.

Bottom left: TP4056,
stuck on with foam tape,
USB-C poking 1 mm past
the bottom edge.

screen's SD holder
above: keep low

Bottom right: DAC, jack
down at the bottom edge.
Its wire row goes in column
N (N34–N39), the other
row in column T (T35–
T40). It overhangs the right
edge by about 1 mm.

Grey dashed area: the
screen's SD-card holder
sits above it. Keep it clear.

charger, stuck on
USB-C ↓ out of edge

Everything under the
screen must stay under 10
mm tall.

Cutting the board: score
along a line of holes on
both sides, 6–8 times with
the box cutter against the
ruler, then snap it over a
table edge and sand. You
need 20 holes across and
43 down.

## Off-board wires: battery, charger, switch

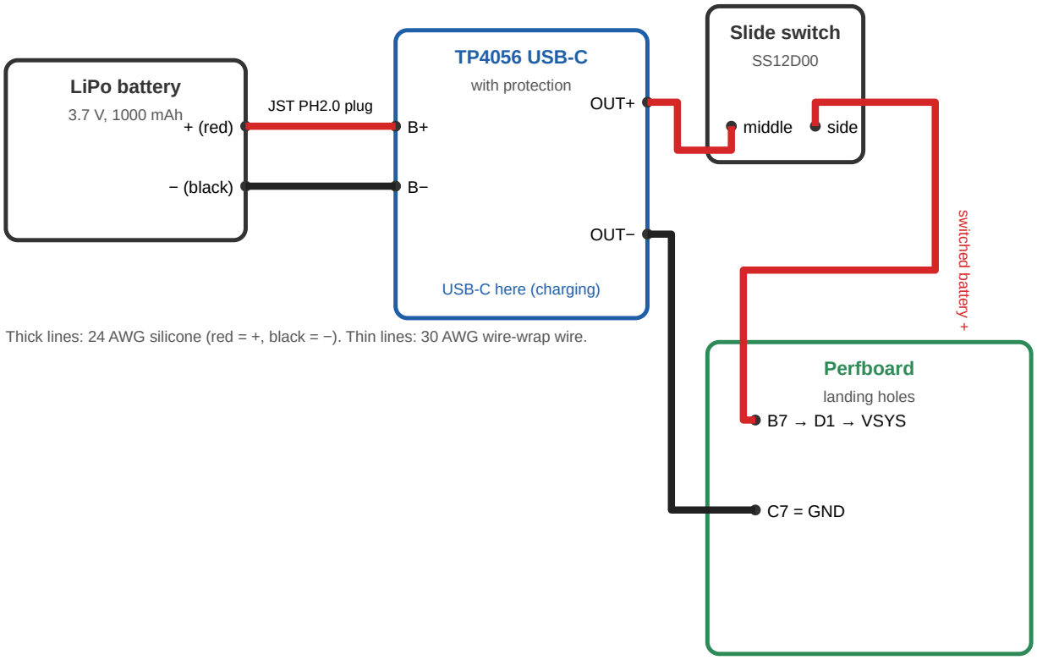
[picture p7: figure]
LiPo battery; 3.7 V, 1000 mAh; + (red); − (black); TP4056 USB-C; with protection; OUT+; OUT−; USB-C here (charging); JST PH2.0 plug; Slide switch; middle; side; Perfboard; landing holes B7 → D1 → VSYS; C7 = GND; switched battery +

Thick lines: 24 AWG silicone (red = +, black = −). Thin lines: 30 AWG wire-wrap wire.

## Build order

1. Cut the board. Solder the two Pico sockets (plug the Pico in first so they line up, then solder).
2. Solder the 1×14 screen socket in row 10. For the 1×4 SD socket: plug it onto the screen's SD pins, plug the screen into the 1×14 socket, push the 1×4 through row 42, then solder. This lines it up exactly.
3. D1, R1, R2, the capacitor and the six solder bridges.
4. The 7 links, then wires 1–10. Test: Pico in, screen on, USB from the laptop only (no battery). Home screen, touch and SD card should work.
5. DAC: pins through N34–N39 and T35–T40, solder, then wires 12–16. Check first: N35 must beep to the jack’s outer metal tab (that pin is GND). Test: play music from the SD card on headphones.
6. Wire 11, then the TP4056, switch and battery wires. Before plugging in the battery: with the multimeter on continuity, check B7 to C7 does not beep, and check red really goes to B+.
7. Plug in the battery, switch on. Kapton tape over the back, then stick the battery on with foam tape.

## Shopping list

Item | Qty | Notes
Perfboard, double-sided, plated holes, 2.54 mm, 9 × 15 cm | 1 | green FR-4, not brown paper board. Cut to 20 × 43 holes.
Female header strip 1 × 40, 2.54 mm (8.5 mm tall) | 3 | Pico 2 × 20, screen 1 × 14, SD 1 × 4. Each cut wastes one pin.
TP4056 charger module, USB-C, with protection | 1–2 | must have 6 pads: IN+, IN−, B+, B−, OUT+, OUT−
LiPo 3.7 V, 1000 mAh, size 503450 (5 × 34 × 50 mm) | 1 | with protection board and JST PH2.0 plug
JST PH2.0 2-pin socket with wires | 1 | matches the battery's plug
Slide switch SS12D00 (3 pins) | 2 | power switch, fitted in the case wall
Schottky diode 1N5819 | 2 | D1
Resistor 100 kΩ, ¼ W | 3 | R1, R2
Ceramic capacitor 100 nF ("104") | 2 | soldered across R2
Wire-wrap wire, 30 AWG (Kynar), 2–3 colours | 1 roll each | all signal wires on the back
Silicone wire, 24 AWG stranded, red + black | 1 m each | battery, charger, switch

Solder 0.6–0.8 mm with flux, flux pen, desolder wick

Kapton tape, double-sided foam tape, 2 mm heat-shrink | | insulate the back before the battery goes on

Tools: temperature-controlled iron (330–350 °C), flush cutters, a stripper that handles 30 AWG, multimeter, box cutter and steel ruler.

## Which wire where

Signals (the 11 numbered wires): 30 AWG wire-wrap wire, single core. Thin, stays where you bend it, and its insulation doesn't melt back when you solder next to it.
Battery, charger, switch: 24 AWG stranded silicone. Flexible, carries over 1 A. Red for +, black for −. Neighbouring holes (marked grey on the back view): join with a blob of solder, or a scrap of cut-off resistor lead.
No Dupont jumper wires in the final build: they're tall and work loose.

## Battery and charging

The battery only connects to the TP4056 (B+ / B−), never straight to the Pico.
TP4056 OUT+ → power switch → D1 → Pico VSYS. D1 stops the Pico's USB from pushing 5 V into the battery, so you can plug in the Pico's micro-USB to flash firmware at any time.
Charge through the TP4056's USB-C. Red LED = charging, blue/green = full. It charges at 1 A, which is fine for a 1000 mAh cell. For a proper full charge, switch the Pod off while it charges.
R1 and R2 halve the battery voltage so GP28 can read it. The firmware needs a small update to show the percentage from this; until then the battery icon stays hidden and everything else works.
Check the plug polarity before connecting: cheap PH2.0 batteries are sometimes wired backwards. Red must reach B+. Never cut both battery wires at once.

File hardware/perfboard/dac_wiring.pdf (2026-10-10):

## Pod: DAC wiring

Taken from Adafruit's own board files, matched to your photos. Turn the board over so the headphone jack end points towards you: the row of 6 pins on the left needs no wires; the row on the right has the 5 pins that do.

DAC pins, seen from the solder side

Where each wire goes on the Pico

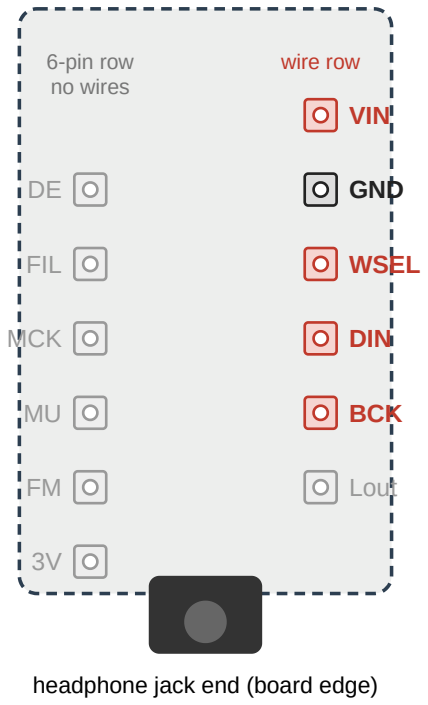
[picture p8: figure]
headphone jack end (board edge); FIL; MCK; VIN; GND; WSEL; DIN; BCK; Lout; 6-pin row no wires; wire row

Row starting at pin 40 (USB end) →

40
VBUS

39
VSYS

38
GND

37
3V3_EN

36
3V3
← VIN

Last 4 pins of the GP0 row (antenna end)

17
GP13

18
GND

19
GP14

20
GP15
↑ DIN ↑ GND ↑ BCK ↑ WSEL

end

The 5 wires

### 1. DAC VIN → Pico pin 36 (3V3)

5th pin from the USB end, row with pin 40

### 2. DAC GND → Pico pin 18 (GND)

3rd pin from the antenna end, GP0 row

### 3. DAC WSEL → Pico pin 20 (GP15)

last pin at the antenna end, GP0 row

### 4. DAC DIN → Pico pin 17 (GP13)

4th pin from the antenna end, GP0 row

### 5. DAC BCK → Pico pin 19 (GP14)

2nd pin from the antenna end, GP0 row

### Before soldering: one 10-second check

1. Multimeter on continuity (beep). One probe on the second pin from the top of the right-hand row.
2. Other probe on the outer metal tab of the headphone jack. It must beep: that pin is GND, so the row is the right way round.
3. If it doesn't beep, stop and send me a photo before wiring.

### Tips

Cut the bent pins down to about 2 mm, then solder each one to its own pad only. Bent pins lying across neighbouring pads can short.
Solder the six left-row pins and Lout too (for strength), but connect nothing to them. The 3V pin especially must stay unconnected.
These Pico pins match the current firmware (pod.uf2): DIN = GP13, BCK = GP14, WSEL = GP15.

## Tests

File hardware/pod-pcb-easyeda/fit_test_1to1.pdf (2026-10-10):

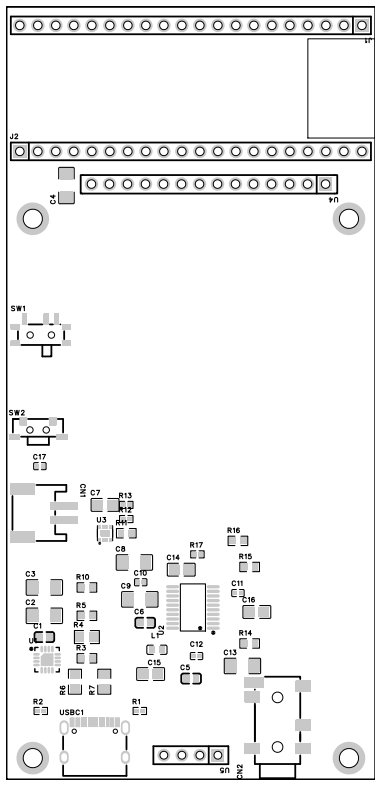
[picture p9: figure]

100 mm check line: must measure exactly 100 mm. If not, the print was scaled.

## Pod PCB, 1:1 fit test (top view)

Print: A4, scale 100% / Actual size (not "Fit to page").
Check: the board must measure 52 × 109 mm, and the line below it 100 mm.

Test 1, Pico 2 W: lay the paper on a piece of cardboard or foam. Press the Pico's header pins through the two rows of circles at the top. All 40 pins should go straight through, with the antenna end over the notch.

Test 2, screen: press the screen module's 14-pin header through the long row below the Pico, then check the 4 SD pins land on the short row at the bottom, and the module's 4 corner holes line up with the 4 big circles.

Test 3, edges: USB-C (bottom left) and the headphone jack (bottom right) should sit at the bottom edge; the slide switch and the button at the left edge.

If any pin misses by more than about half a hole, stop and send me a photo before ordering.

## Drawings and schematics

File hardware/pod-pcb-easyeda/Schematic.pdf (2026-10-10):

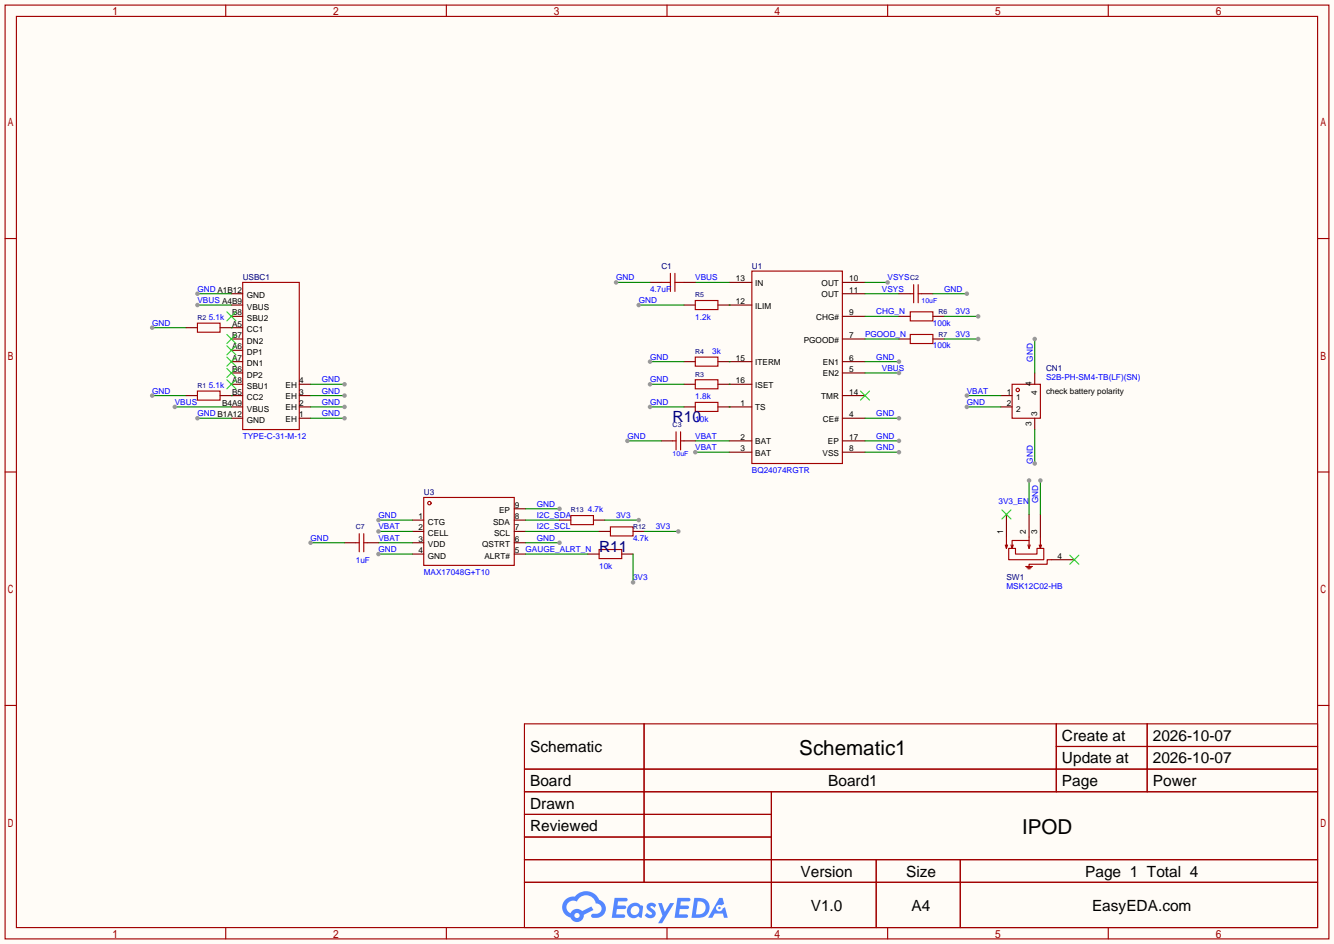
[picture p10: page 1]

Schematic | Schematic1 | Create at | 2026-10-07

Update at | 2026-10-07

Board | Board1 | Page | Power
Drawn | | IPOD
Reviewed

Version | Size | Page 1 Total 4
V1.0 | A4 | EasyEDA.com

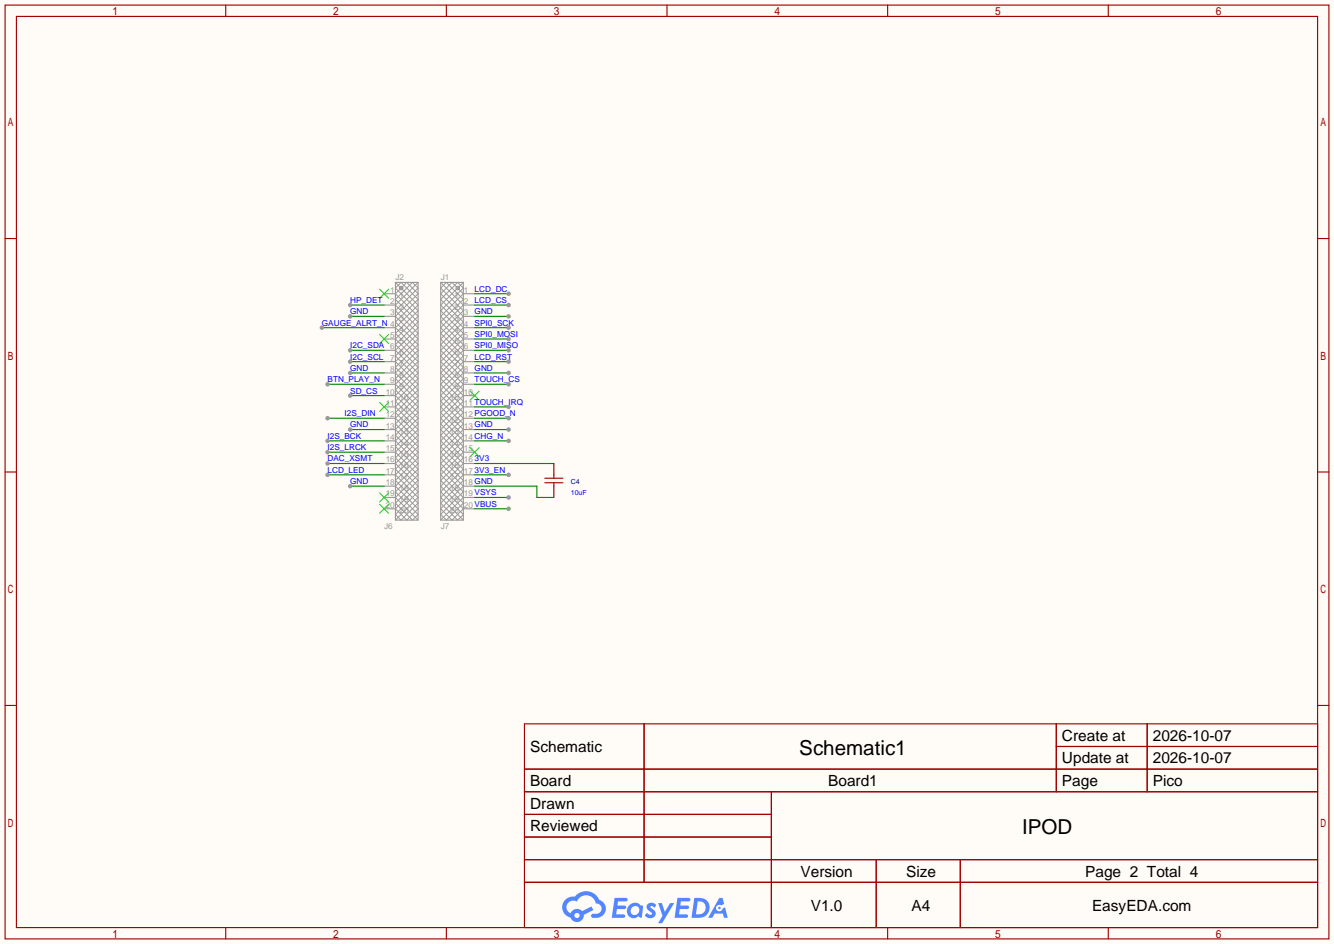
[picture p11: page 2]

Schematic | Schematic1 | Create at | 2026-10-07

Update at | 2026-10-07

Board | Board1 | Page | Pico
Drawn | | IPOD
Reviewed

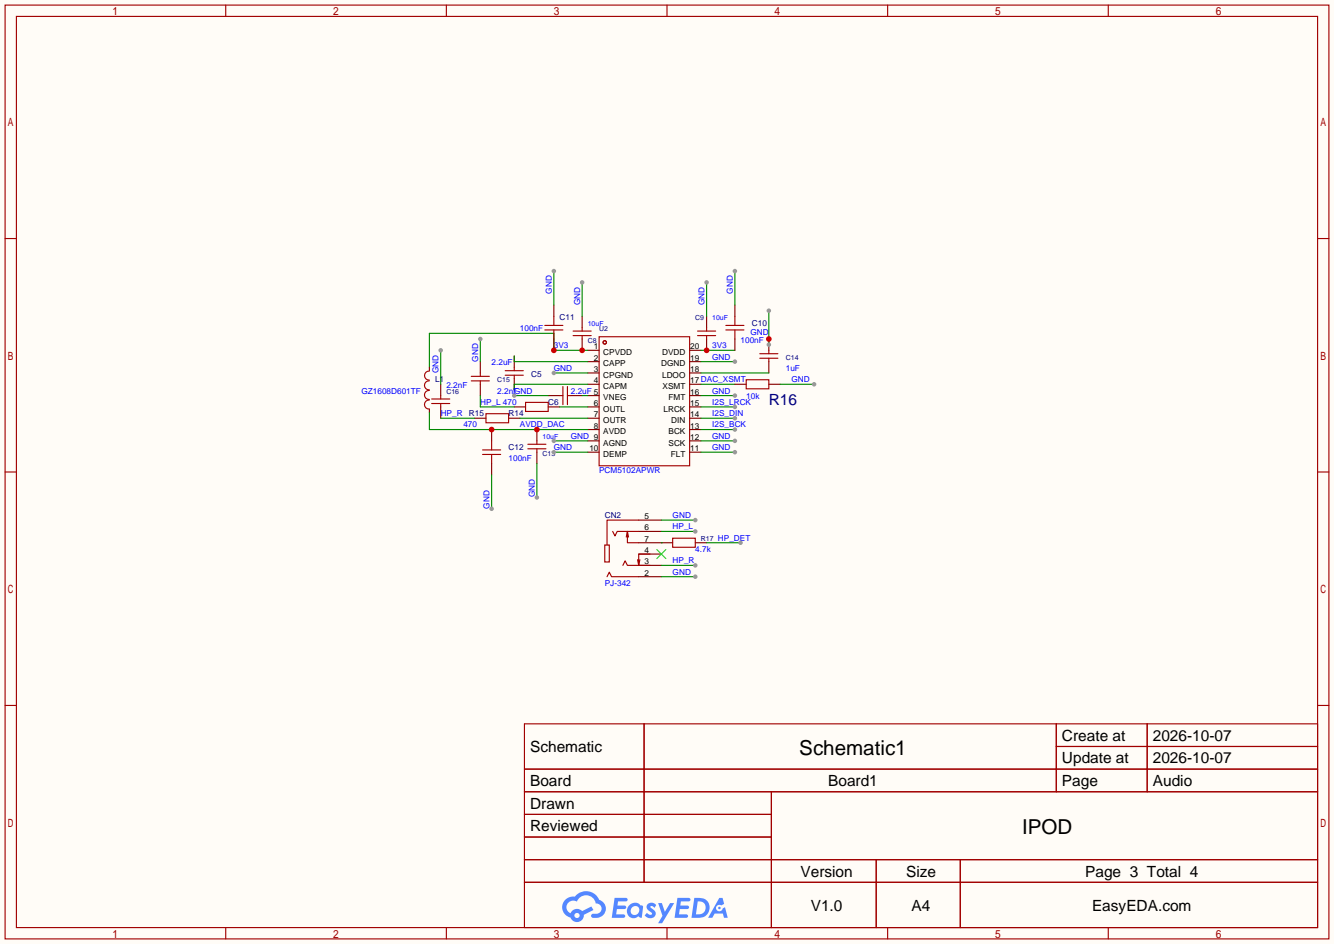
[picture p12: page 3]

Schematic | Schematic1 | Create at | 2026-10-07

Update at | 2026-10-07

Board | Board1 | Page | Audio
Drawn | | IPOD
Reviewed

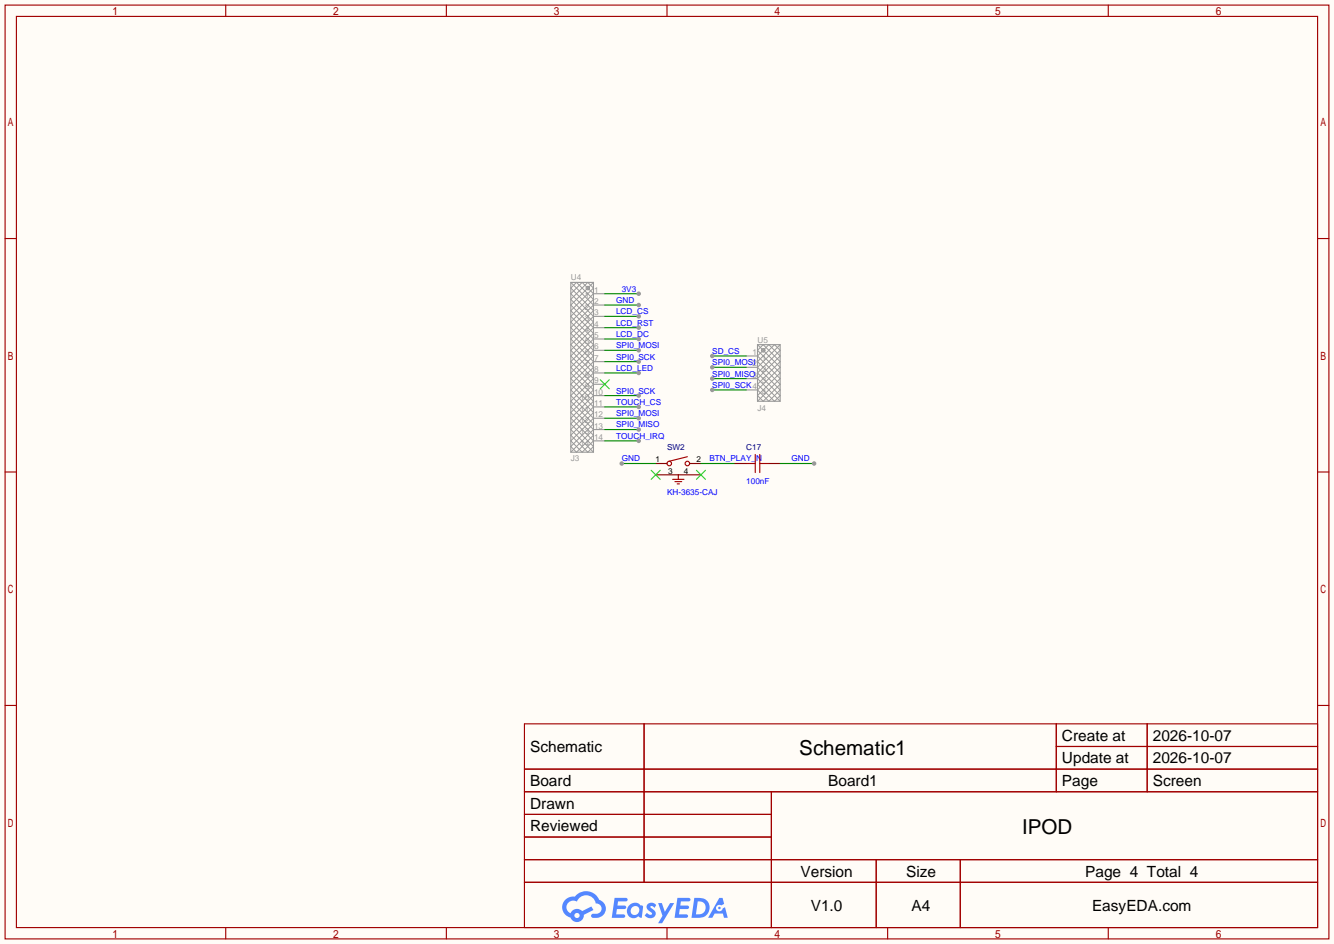
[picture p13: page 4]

Schematic | Schematic1 | Create at | 2026-10-07

Update at | 2026-10-07

Board | Board1 | Page | Screen
Drawn | | IPOD
Reviewed

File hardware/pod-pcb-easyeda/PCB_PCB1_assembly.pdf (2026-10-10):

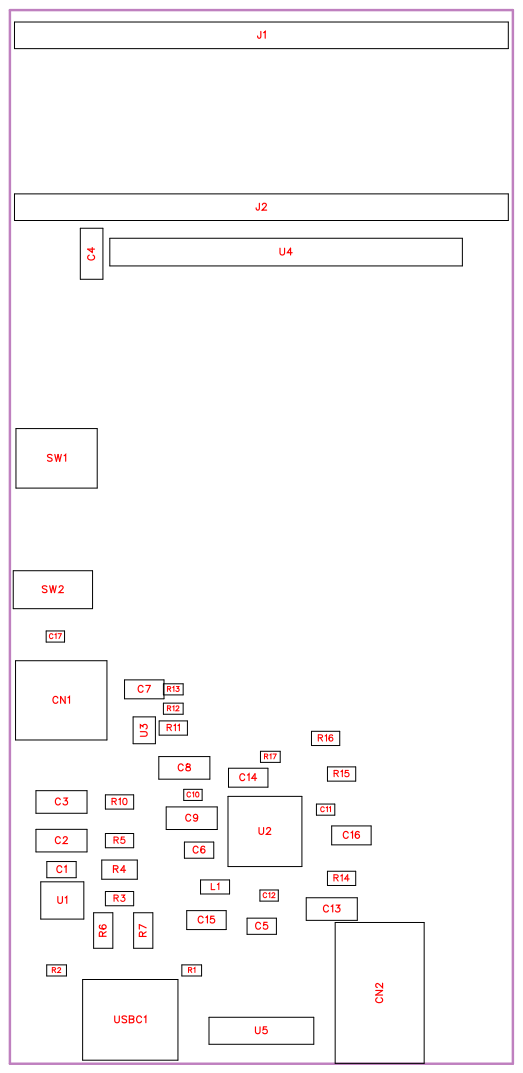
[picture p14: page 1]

No. | Quantity | Comment | Designator | Footprint | Value | Manufacturer Part | Manufacturer | Supplier Part | Supplier
1 | 1 | 4.7uF | C1 | C0603 | 4.7uF | CL10A475K O8NNNC | SAMSUNG( ) 三星 | C19666 | LCSC
2 | 6 | 10uF | C2,C3,C4,C8,C9,C13 | C1206 | 10uF | CL31A106KB HNNNE | SAMSUNG( ) 三星 | C13585 | LCSC
3 | 2 | 2.2uF | C5,C6 | C0603 | 2.2uF | CL10A225K O8NNNC | SAMSUNG( 三星 ) | C23630 | LCSC
4 | 2 | 1uF | C7,C14 | C0805 | 1uF | CL21B105KB FNNNE | SAMSUNG( 三星 ) | C28323 | LCSC
5 | 4 | 100nF | C10,C11,C12,C17 | C0402 | 100nF | CL05B104K O5NNNC | SAMSUNG( 三星 ) | C1525 | LCSC
6 | 2 | 2.2nF | C15,C16 | C0805 | 2.2nF | CL21C222JB FNNNE | SAMSUNG( ) 三星 | C28260 | LCSC
7 | 1 | S2B-PH-SM4 -TB(LF)(SN) | CN1 | CONN-SMD_ P2.00_S2B-P H-SM4-TB-L F-SN | | S2B-PH-SM4 -TB(LF)(SN) | JST | C295747 | LCSC
8 | 1 | PJ-342 | CN2 | AUDIO-SMD _PJ-342_C6 68606 | | PJ-342 | SHOU HAN(首韩 ) | C668606 | LCSC
9 | 1 | GZ1608D601 TF | L1 | L0603 | | GZ1608D601 TF | Sunlord(顺络 ) | C1002 | LCSC
10 | 2 | 5.1k | R1,R2 | R0402 | 5.1k | 0402WGF51 01TCE | UNI-ROYAL( 厚声 ) | C25905 | LCSC
11 | 1 | 1.8k | R3 | R0603 | 1.8k | 0603WAF18 01T5E | UNI-ROYAL( 厚声 ) | C4177 | LCSC
12 | 1 | 3k | R4 | R0805 | 3k | 0805W8F300 1T5E | UNI-ROYAL( 厚声 ) | C17661 | LCSC
13 | 1 | 1.2k | R5 | R0603 | 1.2k | 0603WAF12 01T5E | UNI-ROYAL( ) 厚声 | C22765 | LCSC
14 | 2 | 100k | R6,R7 | R0805 | 100k | 0805W8F100 3T5E | UNI-ROYAL( ) 厚声 | C149504 | LCSC
15 | 3 | 10k | R10,R11,R16 | R0603 | 10k | 0603WAF10 02T5E | UNI-ROYAL( 厚声 ) | C25804 | LCSC
16 | 3 | 4.7k | R12,R13,R17 | R0402 | 4.7k | 0402WGF47 01TCE | UNI-ROYAL( 厚声 ) | C25900 | LCSC
17 | 2 | 470 | R14,R15 | R0603 | 470 | 0603WAF47 00T5E | UNI-ROYAL( 厚声 ) | C23179 | LCSC
18 | 1 | MSK12C02-HB | SW1 | SW-TH_MSK 12C02-HB-1 | | MSK12C02-HB | SHOU HAN(首韩 ) | C431541 | LCSC
19 | 1 | KH-3635-CA J | SW2 | SW-SMD_K H-3635-CAJ | | KH-3635-CA J | kinghelm( 金 ) 航标 | C530670 | LCSC
20 | 1 | BQ24074RG TR | U1 | QFN-16_L3.0 -W3.0-P0.50-TL-EP1.7 | | BQ24074RG TR | TI(德州仪器 ) | C54313 | LCSC
21 | 1 | PCM5102AP WR | U2 | TSSOP-20_L 6.5-W4.4-P0. 65-LS6.4-BL | | PCM5102AP WR | TI(德州仪器 ) | C107671 | LCSC

22 | 1 | MAX17048G +T10 | U3 | TDFN-8_L2.0 -W2.0-P0.50-BL-EP1.2 | MAX17048G +T10 | ADI(亚德诺)/ MAXIM(美信 ) | C2682616 | LCSC
23 | 1 | TYPE-C-31-M-12 | USBC1 | USB-C_SMD -TYPE-C-31-M-12_1 | TYPE-C-31-M-12 | 韩国韩荣 | C165948 | LCSC

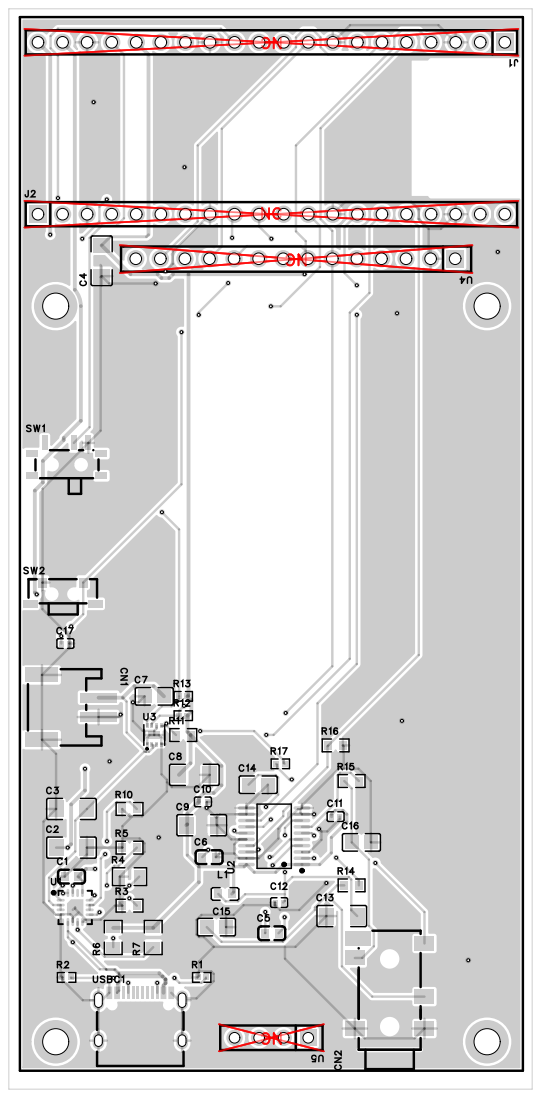
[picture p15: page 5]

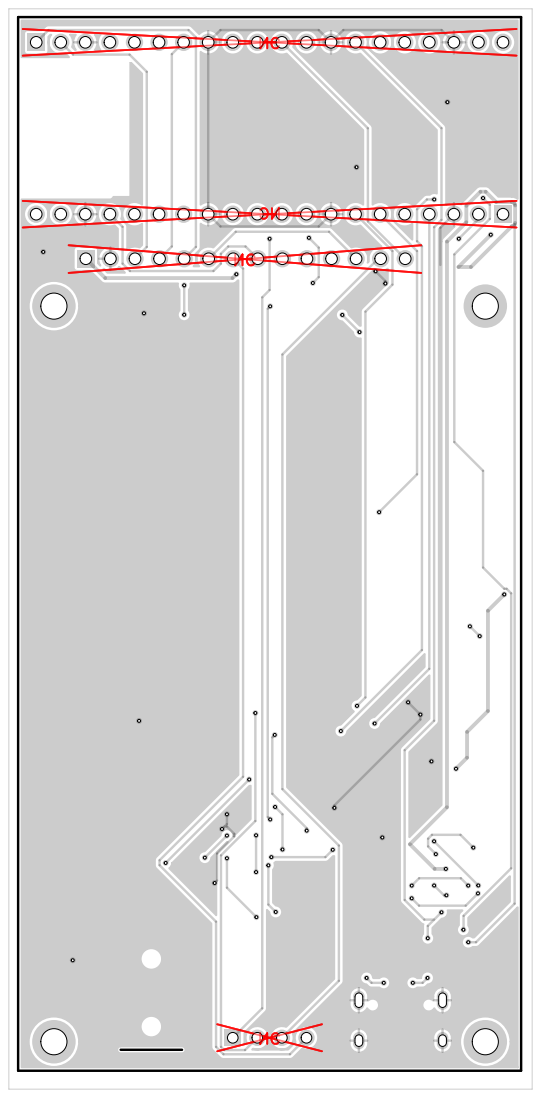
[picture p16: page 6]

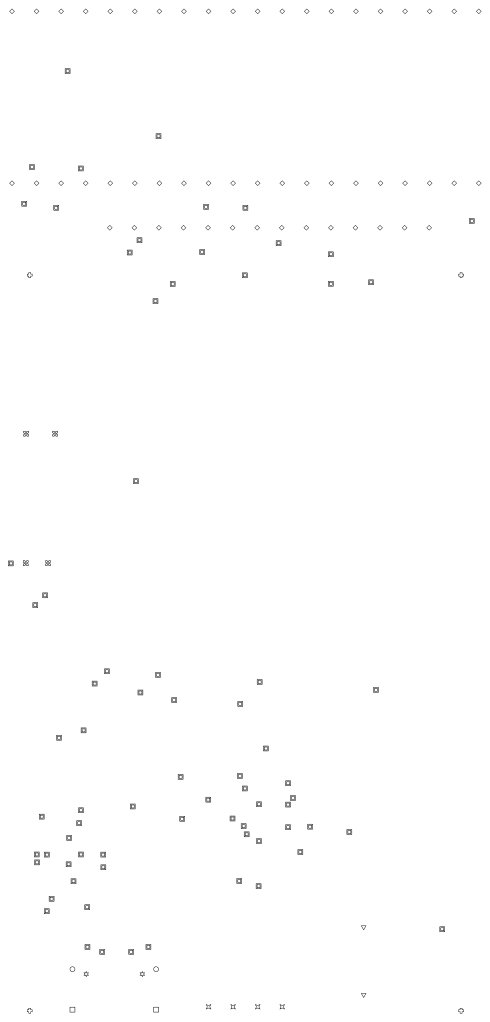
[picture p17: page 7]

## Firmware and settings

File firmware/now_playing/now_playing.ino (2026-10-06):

// Pod: Now Playing (Bluetooth + screen + touch)
// Streams audio from the phone to the DAC and shows the track on the screen,
// with touch buttons for previous / play-pause / next.
//
// Wiring: see README. DAC on GP9/10/11, display + touch on SPI0 (GP18/19/20).

#include <BluetoothAudio.h>
#include <I2S.h>
#include <SPI.h>
#include <Adafruit_GFX.h>
#include <Adafruit_ILI9341.h>
#include <PodTouch.h>

// ---------- Pins ----------
const int PIN_SCK = 18, PIN_MOSI = 19, PIN_MISO = 20;
const int TFT_CS = 17, TFT_DC = 16, TFT_RST = 21, TFT_LED = 13;
const int TOUCH_CS = 22, TOUCH_IRQ = 26;
const int I2S_DATA = 9, I2S_BCLK = 10;   // WSEL is GP11 (BCLK + 1)

// ---------- Colours (RGB565) ----------
const uint16_t BG      = 0x0000;   // black
const uint16_t ACCENT  = 0xF9A6;   // warm coral; later this will come from the album art
const uint16_t TEXT    = 0xFFFF;
const uint16_t SUBTEXT = 0xAD55;   // light grey
const uint16_t DIM     = 0x4208;   // dark grey

I2S i2s(OUTPUT);
A2DPSink a2dp;
Adafruit_ILI9341 tft(&SPI, TFT_DC, TFT_CS, TFT_RST);
PodTouch touch(TOUCH_CS);   // calibration lives in PodTouch

// State shared with Bluetooth callbacks
volatile bool connected = false;
volatile bool trackChanged = true;
volatile bool statusChanged = true;
volatile A2DPSink::PlaybackStatus status = A2DPSink::STOPPED;

void connectCB(void *, bool c) { connected = c; trackChanged = true; statusChanged = true; }
void playbackCB(void *, A2DPSink::PlaybackStatus s) { status = s; statusChanged = true; }
void trackCB(void *) { trackChanged = true; }

// ---------- Layout (portrait 240 x 320) ----------
const int ART_Y = 0, ART_H = 150;        // placeholder area where album art will go
const int TITLE_Y = 166, ARTIST_Y = 196, ALBUM_Y = 218;
const int BTN_Y = 262, BTN_R = 26;       // control row centre and size
const int BTN_PREV_X = 50, BTN_PLAY_X = 120, BTN_NEXT_X = 190;

// Print a string centred on a line, cutting it short with ".." if it is too wide
void centred(const char *s, int y, uint8_t size, uint16_t colour) {
  tft.setTextSize(size);
  tft.setTextColor(colour);
  int maxChars = 240 / (6 * size);
  char buf[48];
  strncpy(buf, (s && *s) ? s : "-", sizeof(buf) - 1);
  buf[sizeof(buf) - 1] = 0;
  if ((int)strlen(buf) > maxChars) {
    buf[maxChars - 2] = '.'; buf[maxChars - 1] = '.'; buf[maxChars] = 0;
  }
  int w = strlen(buf) * 6 * size;
  tft.setCursor((240 - w) / 2, y);
  tft.print(buf);
}

void drawArtPlaceholder() {
  // Vertical fade from the accent colour into black: the "Poster" look, minus the art
  for (int y = 0; y < ART_H; y++) {
    uint8_t r = ((ACCENT >> 11) & 0x1F) * (ART_H - y) / ART_H;
    uint8_t g = ((ACCENT >> 5) & 0x3F) * (ART_H - y) / ART_H;
    uint8_t b = (ACCENT & 0x1F) * (ART_H - y) / ART_H;
    tft.drawFastHLine(0, ART_Y + y, 240, (r << 11) | (g << 5) | b);
  }
  tft.setTextSize(6);
  tft.setTextColor(TEXT);
  tft.setCursor(120 - 18, 45);
  tft.print((char)14);   // music note glyph
}

void drawTrack() {
  tft.fillRect(0, ART_H, 240, BTN_Y - BTN_R - 8 - ART_H, BG);
  if (!connected) {
    centred("Pod", TITLE_Y, 3, TEXT);
    centred("Pair your phone with \"Pod\"", ARTIST_Y + 8, 1, SUBTEXT);
    return;
  }
  centred(a2dp.trackTitle(), TITLE_Y, 2, TEXT);
  centred(a2dp.trackArtist(), ARTIST_Y, 2, ACCENT);
  centred(a2dp.trackAlbum(), ALBUM_Y, 1, SUBTEXT);
}

void drawControls() {
  uint16_t c = connected ? TEXT : DIM;
  tft.fillRect(0, BTN_Y - BTN_R - 2, 240, 2 * BTN_R + 4, BG);

  // Previous: |<<
  tft.fillRect(BTN_PREV_X - 14, BTN_Y - 10, 3, 20, c);
  tft.fillTriangle(BTN_PREV_X - 10, BTN_Y, BTN_PREV_X, BTN_Y - 10, BTN_PREV_X, BTN_Y + 10, c);
  tft.fillTriangle(BTN_PREV_X, BTN_Y, BTN_PREV_X + 10, BTN_Y - 10, BTN_PREV_X + 10, BTN_Y + 10, c);

  // Play / pause in a filled circle
  tft.fillCircle(BTN_PLAY_X, BTN_Y, BTN_R, connected ? ACCENT : DIM);
  if (status == A2DPSink::PLAYING) {
    tft.fillRect(BTN_PLAY_X - 9, BTN_Y - 11, 6, 22, BG);
    tft.fillRect(BTN_PLAY_X + 3, BTN_Y - 11, 6, 22, BG);
  } else {
    tft.fillTriangle(BTN_PLAY_X - 7, BTN_Y - 12, BTN_PLAY_X - 7, BTN_Y + 12, BTN_PLAY_X + 12, BTN_Y, BG);
  }

  // Next: >>|
  tft.fillTriangle(BTN_NEXT_X - 10, BTN_Y - 10, BTN_NEXT_X - 10, BTN_Y + 10, BTN_NEXT_X, BTN_Y, c);
  tft.fillTriangle(BTN_NEXT_X, BTN_Y - 10, BTN_NEXT_X, BTN_Y + 10, BTN_NEXT_X + 10, BTN_Y, c);
  tft.fillRect(BTN_NEXT_X + 11, BTN_Y - 10, 3, 20, c);
}

void setup() {
  Serial.begin(115200);

  // Screen + touch on the shared SPI0 bus
  SPI.setSCK(PIN_SCK);
  SPI.setTX(PIN_MOSI);
  SPI.setRX(PIN_MISO);
  pinMode(TFT_LED, OUTPUT);
  digitalWrite(TFT_LED, HIGH);
  tft.begin();
  tft.setRotation(0);
  tft.setTextWrap(false);
  tft.fillScreen(BG);
  touch.begin();
  touch.threshold = 60;

  drawArtPlaceholder();

  // Bluetooth audio into the DAC
  i2s.setBCLK(I2S_BCLK);
  i2s.setDATA(I2S_DATA);
  i2s.setBitsPerSample(16);
  a2dp.setName("Pod");
  a2dp.setConsumer(new BluetoothAudioConsumerI2S(i2s));
  a2dp.onConnect(connectCB);
  a2dp.onPlaybackStatus(playbackCB);
  a2dp.onTrackChanged(trackCB);
  a2dp.begin();
}

String shownTitle;
bool wasTouched = false;
unsigned long lastPoll = 0;

void handleTap(int x, int y) {
  if (!connected || abs(y - BTN_Y) > BTN_R + 10) return;
  if (abs(x - BTN_PREV_X) < 32) {
    a2dp.backward();
  } else if (abs(x - BTN_PLAY_X) < 36) {
    if (status == A2DPSink::PLAYING) a2dp.pause(); else a2dp.play();
  } else if (abs(x - BTN_NEXT_X) < 32) {
    a2dp.forward();
  }
}

void loop() {
  // Redraw only what changed; drawing is slow compared with audio
  const char *t = a2dp.trackTitle();
  if (t && shownTitle != t) { shownTitle = t; trackChanged = true; }
  if (trackChanged)  { trackChanged = false;  drawTrack(); }
  if (statusChanged) { statusChanged = false; drawControls(); }

  // Touch: act once per press, on the moment the finger lands
  if (millis() - lastPoll < 20) return;
  lastPoll = millis();
  PodTouchPoint p;
  bool isTouched = touch.read(p);
  if (isTouched && !wasTouched) handleTap(p.x, p.y);
  wasTouched = isTouched;

  // BOOTSEL still works as play / pause
  if (BOOTSEL) {
    if (status == A2DPSink::PLAYING) a2dp.pause(); else a2dp.play();
    while (BOOTSEL) delay(10);
  }
}

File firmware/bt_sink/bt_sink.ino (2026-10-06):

// Pod: Bluetooth audio receiver (A2DP sink)
// Pair your phone with "Pod", play music, and it comes out of the PCM5102 DAC.
// Wiring: DIN -> GP9, BCK -> GP10, WSEL (LRCK) -> GP11.
//
// Onboard LED: slow blink = waiting for a phone, steady on = connected.
// BOOTSEL button: pause / resume.
// Track title and artist are printed to the Serial Monitor (115200 baud).

#include <BluetoothAudio.h>
#include <I2S.h>

I2S i2s(OUTPUT);
A2DPSink a2dp;

volatile bool connected = false;
volatile A2DPSink::PlaybackStatus status = A2DPSink::STOPPED;

void connectCB(void *param, bool isConnected) {
  (void) param;
  connected = isConnected;
  Serial.printf(isConnected ? "Phone connected\n" : "Phone disconnected\n");
}

void playbackCB(void *param, A2DPSink::PlaybackStatus state) {
  (void) param;
  status = state;
}

void volumeCB(void *param, int pct) {
  (void) param;
  Serial.printf("Volume: %d%%\n", pct);
}

void setup() {
  Serial.begin(115200);
  pinMode(LED_BUILTIN, OUTPUT);

  i2s.setBCLK(10);   // BCK on GP10, so WSEL is automatically GP11
  i2s.setDATA(9);    // DIN on GP9
  i2s.setBitsPerSample(16);

  a2dp.setName("Pod");
  a2dp.setConsumer(new BluetoothAudioConsumerI2S(i2s));
  a2dp.onConnect(connectCB);
  a2dp.onPlaybackStatus(playbackCB);
  a2dp.onVolume(volumeCB);
  a2dp.begin();

  Serial.printf("Pod is ready. Pair your phone with \"Pod\".\n");
}

String lastTitle;
unsigned long lastBlink = 0;

void loop() {
  // LED: steady when connected, slow blink while waiting
  if (connected) {
    digitalWrite(LED_BUILTIN, HIGH);
  } else if (millis() - lastBlink > 500) {
    lastBlink = millis();
    digitalWrite(LED_BUILTIN, !digitalRead(LED_BUILTIN));
  }

  // BOOTSEL = pause / resume
  if (BOOTSEL) {
    if (status == A2DPSink::PLAYING) {
      a2dp.pause();
    } else if (status == A2DPSink::PAUSED) {
      a2dp.play();
    }
    while (BOOTSEL) {
      delay(10);
    }
  }

  // Print the track whenever it changes
  const char *title = a2dp.trackTitle();
  if (title && lastTitle != title) {
    lastTitle = title;
    Serial.printf("Now playing: %s - %s\n", a2dp.trackTitle(), a2dp.trackArtist());
  }
}

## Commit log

2026-10-06 Add GitHub Actions firmware build, blink and DAC tone test sketches
    The build workflow compiles every sketch in firmware/ for the Pico 2 W
    using arduino-cli and the arduino-pico core, and publishes the .uf2
    files as a downloadable artifact. This sidesteps local compiler issues.
    Claude-Session: https://claude.ai/code/session_01DRxt8QzQ72ypvJY6iWLH7J
    [tone_test.ino]
2026-10-06 Add Bluetooth A2DP sink sketch, per-sketch board options, build log
    - bt_sink: receives audio from a phone over Bluetooth as "Pod" and plays
    it through the PCM5102 DAC; LED shows connection state, BOOTSEL
    pauses/resumes, track info goes to Serial
    - Build workflow honours a sketch.yaml default_fqbn so bt_sink compiles
    with the Bluetooth stack enabled
    - PROGRESS.md and README updated for the first working firmware
    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
2026-10-06 Add display and touch test, library install step; log Bluetooth success
    - display_test: backlight, colour fill, title screen and touch dots with
    raw coordinates for calibration (ILI9341 + XPT2046 on shared SPI0)
    - Build installs the libraries listed in firmware/libraries.txt
    - PROGRESS.md: bt_sink confirmed working with the iPhone
    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
2026-10-06 Calibrate touch, add Now Playing firmware
    - Touch calibration from measured corners: both axes are reversed
    (raw X 3540 left -> 565 right, raw Y 3680 top -> 380 bottom)
    - now_playing: Bluetooth audio plus a Now Playing screen with title,
    artist, album, a Poster-style gradient placeholder for album art,
    and touch buttons for previous / play-pause / next
    - README and PROGRESS updated
    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
    [display_test.ino, now_playing.ino]
2026-10-06 Add PodTouch driver for lighter touch
    XPT2046_Touchscreen ignores presses below a hard-coded pressure of 300,
    so taps needed a firm push. PodTouch reads the XPT2046 directly with an
    adjustable threshold (default 120), requires two consecutive readings to
    reject noise, averages extra samples for a steadier position, and maps
    straight to screen pixels using the measured calibration.
    - display_test shows live pressure vs threshold for tuning
    - now_playing uses PodTouch
    - Build passes firmware/libraries to arduino-cli
    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
    [display_test.ino, now_playing.ino]
2026-10-06 Add main Pico SDK firmware with album art (Poster UI)
    Recovered from an earlier design session and added as sdk/:
    - Bluetooth A2DP sink on BTstack with software volume, sample-rate
    handling and AVRCP Cover Art download on every track change
    - Poster Now Playing screen rendered on core 1: full-bleed art fading
    into an accent colour, anti-aliased Inter text, progress bar, touch
    controls; touch calibration stored in flash
    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
2026-10-06 Add Pod-side volume slider and press-and-hold seeking
    - Tap the album art to open a volume slider over it; dragging sets the
    output gain and notifies the phone (AVRCP absolute volume), so the
    iPhone slider follows. Rate-limited to one update per 120 ms.
    - Press and hold prev/next to rewind/fast-forward via AVRCP
    press-and-hold; the button highlights while scrubbing and the
    progress bar re-syncs on release.
    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
2026-10-06 Add home screen, SD card player and battery gauge
    - Home screen picks Phone (Bluetooth) or SD card; top-left tap returns
    - SD mode (sdk/sd_player): FatFs read-only (FAT32 + exFAT) over an SPI
    SD driver, library browser with sorted folders/songs and touch
    scrolling, MP3 via minimp3 and 16/24-bit WAV, ID3v2/v1 + WAV INFO
    tags, embedded or folder cover art, Xing/VBRI duration and VBR seek,
    drag-to-seek, hold-to-scrub, auto-advance through a folder
    - pod_spi_lock: display, touch and SD share SPI0; display blits release
    the bus every 24 rows so SD reads never stall audio
    - Battery icon and one-shot "Battery low" toast below 15 % from a
    MAX17048 fuel gauge on I2C0 (hidden when no gauge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
2026-10-06 Add PCB, battery and enclosure plan
    docs/pcb-plan.md: chip-down RP2350 + RM2 vs Pico 2 W module, 2.0"
    capacitive IPS screen, PSRAM, USB-C + BQ24074 power-path charger +
    protected LiPo + MAX17048 gauge + TPS63802 buck-boost, battery-life
    estimates, pin map, stack-up, KiCad step-by-step, bring-up and case plan.
    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
2026-10-07 Make going back to the home screen easy
    - House-icon Home button on Now Playing (both modes) and in the SD
    library header, with a 52 px tall touch area (the top edge is where
    resistive touch is least precise); "< Library" is now a separate button
    - "Going home..." message shows instantly while the Pod restarts
    - Library back arrow only appears inside sub-folders
    - Touch recalibration needs a 1.5 s hold at power-up, so a tap during
    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
2026-10-07 PCB Rev A: lock decisions, full spec, start KiCad project
    - docs/pcb-plan.md rewritten as the Rev A spec: RP2350A + RM2, 2.8"
    module on sockets, 1000 mAh LiPo, play/pause button + power switch;
    parts list, every connection per sheet (values checked against the
    BQ24074, TPS63802 and RM2 datasheets), GPIO map, layout with an
    antenna tab, routing rules, bring-up and enclosure steps
    - hardware/pod-pcb: KiCad project with five hierarchical sheets (each
    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
    [audio.kicad_sch, mcu.kicad_sch, pod-pcb.kicad_pcb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]
2026-10-07 PCB: place screen module holes and headers from measurements
    - Module positions measured from a photo of the MSP2807 V1.2 module:
    M2.5 holes, J3 14-pin and J4 4-pin SD header positions, and the SD
    card holder, mirrored onto our board (module faces down onto it)
    - Pin markers, pin-1 marks, SD holder keep-clear area and a 50 mm
    scale bar on the board drawing layer
    - docs/screen_template_1to1.pdf: printable 1:1 check template
    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
    [audio.kicad_sch, mcu.kicad_sch, pod-pcb.kicad_pcb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]
2026-10-07 PCB: battery moves to the underside of the board
    The screen module's microSD holder occupies the gap under the module,
    so the 1000 mAh cell no longer fits beside it. It now sits on the
    underside of our board (one-sided assembly, no parts on the bottom),
    with its lead through a notch to J2. Pod is about 55 x 100 x 24 mm.
    Layout, case and progress notes updated; battery outline on B.Fab.
    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
    [audio.kicad_sch, mcu.kicad_sch, pod-pcb.kicad_pcb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]
2026-10-07 Add EasyEDA workflow guide for the Rev A board
    docs/easyeda-guide.md: EasyEDA Pro setup (4-layer, JLC rules, five
    sheets joined by net labels), parts to search by MPN, sheet order with
    tips, layout steps with the measured fixed positions and keep-outs,
    ordering with JLCPCB assembly, and what to export for review.
    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
2026-10-07 EasyEDA guide: rewrite as a beginner walkthrough with click-by-click Power sheet checklist
    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
2026-10-07 Power: ISET resistor 1.78k -> 1.8k (standard value, JLCPCB Basic part)
    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
    [power.kicad_sch]
2026-10-07 Power: ILIM resistor 1.1k -> 1.2k (1.34 A input limit, Basic part)
    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
    [power.kicad_sch]
2026-10-07 Power: TPS63802 FB divider 510k/91k -> 56k/10k (still 3.30 V, Basic parts)
    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
    [power.kicad_sch]
2026-10-07 Power sheet reviewed; add MCU page checklist (RP2350A minimal design) to EasyEDA guide
    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
2026-10-07 PCB Rev A: use a soldered-on Pico 2 W instead of RP2350A + RM2
    Board 52 x 109 mm, 2 layers, Pico in a top strip with the 9 x 14 mm antenna
    cut-out; power via BQ24074 -> Pico VSYS, switch on 3V3_EN. Spec, EasyEDA guide
    and to-scale layout drawing updated; KiCad skeleton marked superseded.
    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
2026-10-07 Pico footprint: draw it as two 1x20 through-hole headers (J6/J7)
    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
2026-10-07 Guide: Pico header part = LCSC C50981 (1x20 2.54 mm TH)
    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
2026-10-07 Audio page: checklist; jack changed to SJ-43515TS (tip switch) with 4.7k on HP_DET
    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
2026-10-08 Perfboard pin map: 7 screen pins on direct links, battery on GP28
    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
2026-10-10 Add PCB fab files, DAC sheet and guide scripts; log perfboard progress
    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
    [BOM_PCB1.xlsx, PickAndPlace_PCB1.xlsx]
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2026-10-10 Revert pod.uf2 touch handling to the build that works on the perfboard
    Touch detection and calibration are back to the T_IRQ-based code from
    e03cc82, which Ash confirmed registers touches on the built device. The
    later pressure-based experiments are dropped; pod_touch_doctor and
    pod_touch_setup stay as stand-alone diagnostics.
    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
2026-10-10 I2S: swap DIN/BCK/WSEL pin roles to match the rotated DAC wiring on the perfboard
    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
2026-10-10 Revert "I2S: swap DIN/BCK/WSEL pin roles to match the rotated DAC wiring on the perfboard"
    This reverts commit cbba51d89748c63bea39d3a86e3be2fcc37b925a.
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
